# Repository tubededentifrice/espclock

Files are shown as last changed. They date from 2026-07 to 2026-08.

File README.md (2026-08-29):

# ESPClock

A small, child-friendly travel clock: plug it into USB-C and it immediately shows the best time it has, then quietly tries to improve it from an authorized phone or the Internet.

The reference solderless prototype uses a **full-size 38-pin ESP32 DevKit**, a
**0.96-inch 128x64 I2C OLED**, and a **BH1750/GY-302**. A DS3231 is optional for
this bring-up: once synchronized, the ESP keeps time while USB power remains
connected. The compact travel build uses an **ESP32-C3 Super Mini**, preferably
with a larger 1.2-inch TM1637 display and a battery-backed DS3231 after the
behavior has been proven on the bench. The firmware also supports the **ESP32-C3
Super Mini Plus** with a 128x64 OLED. Its dedicated profile keeps the onboard
GPIO8 RGB LED dark.

## Printable case

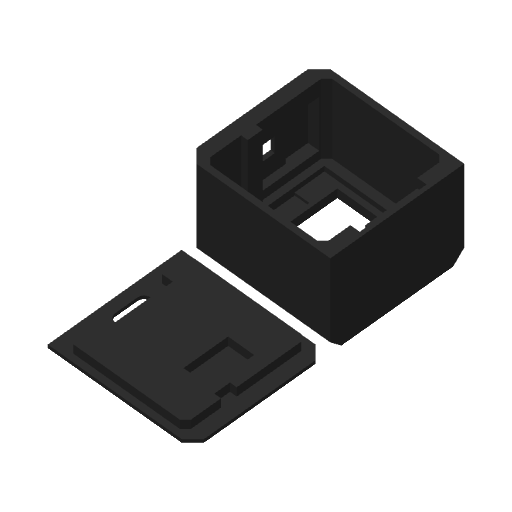
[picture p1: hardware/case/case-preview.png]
ESPClock printable case print plate


The case is checked in as the editable
[Fusion 360 design](hardware/case/esp-clock-case.f3d), a ready-to-slice
[3MF print project](hardware/case/esp-clock.3mf), and individual component
meshes for the [front](hardware/case/front.stl),
[back](hardware/case/back.stl), and [small part](hardware/case/cache.stl).
Use the 3MF for the prepared print plate. The STL files keep design coordinates
and can need placement in the slicer. The preview above comes from the 3MF
print project. This is the current prototype enclosure. Complete the enclosure,
RF, thermal, drop, and child-access acceptance checks below before you use it
as a finished child-facing case.

## What it does

1. Reads UTC from a DS3231 when one is fitted and valid; otherwise it starts
   without inventing a time and waits for a synchronization source.
2. Advertises `ESPClock-xxxx` over BLE continuously. On a clock without a
   selected synchronization route, BLE runs alone for the first 10 seconds.
3. From 10 seconds until two minutes after boot, also offers the no-install
   `ESPClock-xxxx` captive portal while BLE remains available. Loading its
   page transfers the phone's time and offset automatically.
4. If neither phone route succeeds by two minutes, tries open Wi-Fi access
   points in signal-strength order for a bounded window and requests UTC from
   NTP. If NTP is blocked by a captive portal, it makes one bounded,
   synthetic-data-only attempt to accept up to three ordinary guest/terms
   forms, then retries NTP once. A failed BSSID is never retried in that boot.
5. Persists the first successful route. BLE routes refresh every six hours;
   portal and NTP routes wait 24 hours and give BLE a 90-second opportunity
   before using Wi-Fi again. A later successful BLE update promotes any Wi-Fi
   route to BLE and immediately stops Wi-Fi.
6. Keeps time in the ESP while powered and mirrors it to an available RTC.
7. Samples room light about once per second, filters it over several seconds,
   and adjusts the display through eight brightness levels.

Radio failures never stop the clock or blank a valid display.

## Important phone/Bluetooth reality

Approving a Bluetooth pairing authorizes a connection; it does not universally make a phone publish its clock or Internet connection.

- Android does not expose the BLE Current Time Service as a universal system service.
- Generic BLE accessories usually need a phone app to initiate their custom GATT exchange.
- The ESP32-C3 has BLE, not Bluetooth Classic PAN, so it cannot consume Bluetooth tethering.
- NTP provides UTC only. It does not reveal the local timezone.

The repository therefore includes an iOS 18+ [companion app](ios/README.md), an encrypted/bonded BLE write service, and a universal no-app captive-portal fallback. The app uses AccessorySetupKit onboarding and keeps a separate low-duty connection to each authorized clock that has automatic sync enabled, so each clock can request time about every six hours. The app sets no fixed clock-count limit, but iOS radio and memory resources determine the practical number of simultaneous connections. Each clock remembers which route first synchronized it and avoids powering unrelated Wi-Fi paths afterward. BLE remains available as the only automatic route upgrade. Open Wi-Fi/NTP refreshes UTC but retains the last phone-confirmed UTC offset. Concurrent updates are arbitrated atomically in the order BLE, portal, then NTP, so a lower-trust callback cannot overwrite a pending higher-trust update.

This is an honest limit of phone operating systems and profiles, not an ESP32 coding omission. See [hardware research](docs/hardware-research.md) and the [adversarial design review](docs/design-review.md) for sources and deeper tradeoffs.

## Hardware choice

| Board option | Wi-Fi | Bluetooth | Size/fit | Decision |
|---|---:|---:|---|---|
| **ESP32 38-pin** | **Yes** | **Classic + BLE** | Breadboard-friendly, usually Micro-USB | **Selected for the first solderless prototype** |
| **ESP32-C3 Super Mini** | **Yes** | **BLE 5** | **About 22.5 × 18 mm, USB-C** | **Selected** |
| ESP32-C3 Super Mini Plus | Yes | BLE 5 | Same small C3 format; onboard RGB LED and external-antenna connector | Supported 128x64 OLED variant |
| S2 Mini | Yes | No | Small | Rejected: no Bluetooth |
| C6 Mini N4 | Yes, including Wi-Fi 6 | BLE 5.3 | Small | Works, but its extra radios add no clock benefit |

The C3 has enough GPIO, flash, RAM, and radio capability without the size of
the 38-pin board, so it remains the travel target. The firmware has distinct,
pin-safe PlatformIO profiles for both board families and for TM1637, SSD1306
128x64, and SSD1306 128x32 displays.

For OLED bench bring-up, start with the **0.96-inch 128x64** unit. The narrow
0.91-inch module is normally 128x32; with the same 128-pixel width but half as
many rows, its digits are substantially shorter. Neither tiny OLED is
guaranteed readable from two metres, and continuously displayed OLED pixels can
age, so the physical distance/night test decides whether either is suitable for
the final clock. The display backend is modular, so that test does not lock the
firmware to one screen.

## Bill of materials

Prices were checked on **2026-07-25** and are approximate. This regional
snapshot uses UAE prices in AED for a consistent comparison; it does not assume
contributors are in the UAE. Search links and a more detailed comparison are
in [docs/hardware-research.md](docs/hardware-research.md).

| Qty | Part / role | What to buy | Approx. AliExpress | Approx. Amazon.ae |
|---:|---|---|---:|---:|
| 1 | 38-pin ESP32 DevKit | Reference breadboard target | AED 15–30 | AED 25–55 |
| 1 | 0.96-inch SSD1306 OLED, 128x64 | Default bench display, normally `0x3C` | AED 5–12 | AED 15–35 |
| 1 | 0.91-inch SSD1306 OLED, normally 128x32 | Optional comparison display | AED 4–10 | AED 15–30 |
| 1 | BH1750/GY-302 light sensor | Ambient-light input; default address `0x23` | AED 3–8 | AED 10–30 |
| 1 | ESP32-C3 Super Mini or Super Mini Plus | Compact travel target; Plus has an onboard RGB LED | AED 9–18 | AED 20–45 |
| 1 | 1.2-inch red TM1637 clock display | Optional final-display candidate; centre colon | AED 15–40 | AED 35–70 |
| 1 | DS3231 RTC module | Optional for bring-up, required for unplugged retention; verify a non-charging CR2032 arrangement | AED 6–15 | AED 20–45 |
| 1 | Branded CR2032 | Primary, non-rechargeable coin cell | AED 2–5 | AED 5–10 |
| 1 | 5 × 7 cm, 2.54 mm perfboard | Single-sided is sufficient | AED 3–7 | AED 10–20/pack |
| 2 | Female socket strips | Socket the C3 | AED 1–3 | AED 8–15/pack |
| 1 each | 100 µF ≥10 V electrolytic; 100 nF ceramic | Local decoupling | AED 1–2 | Usually in an assortment |
| 1 | USB-C cable and certified 5 V/1 A supply | Use a data-capable cable for flashing | Varies | AED 15–35 |
| — | Solid wire, solder, heat-shrink, smoked red window | Workshop consumables | AED 3–8 allocated | AED 10–25 |

A new bench build using the default ESP32/OLED/BH1750 configuration is roughly
**AED 23–50** from AliExpress. A compact travel build with the C3, TM1637,
BH1750, RTC/cell, perfboard, sockets, and decoupling is roughly **AED 40–98**.
Both estimates exclude shipping, enclosure, cable, and power supply.

Optional only if the exact large display fails its 3.3 V acceptance test: a two-channel BSS138 level-shifter module, approximately AED 2–8.

## Wiring

For the first solderless test, power the OLED and BH1750 from the full-size
ESP32's regulated **3.3 V** rail:

| 38-pin ESP32 | Connect to | Notes |
|---|---|---|
| `3V3` | OLED `VCC`; BH1750 `VCC`; optional DS3231 `VCC` | Keep every I2C pull-up at 3.3 V |
| `GND` | Every module `GND` | One common ground |
| GPIO21 | OLED `SDA`; BH1750 `SDA`; optional DS3231 `SDA` | Shared I2C data |
| GPIO22 | OLED `SCL`; BH1750 `SCL`; optional DS3231 `SCL` | Shared I2C clock |
| GPIO0 | Existing BOOT button only | Five-second powered-on recovery gesture |

Follow the labels printed on the board. Many 38-pin DevKits occupy nearly the
whole breadboard width; use two joined breadboards or jumper one pin row to a
second breadboard if necessary.

The compact TM1637 travel wiring remains:

| ESP32-C3 pin | Connect to | Notes |
|---|---|---|
| `3V3` | TM1637 `VCC`; BH1750 `VCC`; DS3231 `VCC` | Never connect to 5 V |
| `GND` | Every module `GND` | One common ground |
| GPIO4 | TM1637 `CLK` | Dedicated display bus |
| GPIO3 | TM1637 `DIO` | Dedicated display bus |
| GPIO6 | BH1750 `SDA`; DS3231 `SDA` | Shared I2C data |
| GPIO7 | BH1750 `SCL`; DS3231 `SCL` | Shared I2C clock |

Do not attach modules to C3 strapping pins GPIO2/8/9 or native-USB GPIO18/19.
The 128x64 or 128x32 OLED can replace the TM1637 on the C3 by joining it to the
same GPIO6/7 I2C bus. On the Super Mini Plus, GPIO8 drives the onboard WS2812
RGB LED. The dedicated Plus profile sends an all-zero frame after boot. The
power indicator is connected to the power rail and firmware cannot turn it off.

### Travel-build wiring diagram

ESPClock ESP32-C3 Super Mini travel-build wiring

The drawing shows the common top-view Super Mini header order, the four
firmware-selected GPIO connections, both 3.3 V decoupling capacitors, and the
RTC charge-path warning. It also shows the supported 0.96-inch SSD1306 128x64
OLED and notes that the 128x32 OLED uses the same four wires; choose the matching
compile-time profile and fit one display type. This is a routing guide rather
than a 1:1 perfboard artwork; open the image for the full-size SVG and verify
the labels on the exact boards before soldering.

The complete net list, schematic, continuity procedure, level-shifter fallback, and mechanical notes are in [hardware/wiring.md](hardware/wiring.md).

### Mandatory RTC safety check

Many cheap blue ZS-042/HW-111 DS3231 modules try to charge the coin cell through a resistor and diode. A CR2032 is **not rechargeable**.

Before installing a CR2032:

1. prove the module has no charging path, or remove its charge resistor/diode;
2. power the RTC at 3.3 V without a cell and inspect/measure the holder;
3. install the cell, re-power, and verify its voltage is not being driven upward;
4. place it behind a screwed enclosure where a child cannot reach it.

Do not build the clock if this check is uncertain.

### Display voltage acceptance

Running a red TM1637 module at 3.3 V is simple and prevents 5 V pull-ups from reaching the ESP. The TM1637 manufacturer's guaranteed electrical table is specified at higher voltage, so the exact purchased 1.2-inch module must pass:

- repeated cold starts;
- all-segments/full-brightness operation during Wi-Fi transmit;
- two-metre daylight readability;
- minimum-brightness dark-room comfort.

If it fails, follow the 5 V plus BSS138 level-shifter alternative in [hardware/wiring.md](hardware/wiring.md). Never connect a 5 V-powered TM1637 module directly to C3 pins.

## Breadboard bring-up

1. Place the full-size ESP32 on a breadboard and connect the 0.96-inch OLED and
   BH1750 using GPIO21/22. Leave the DS3231 disconnected.
2. Flash `esp32-devkit-oled-128x64`, synchronize from the iPhone app or portal,
   and confirm the clock continues while USB stays powered.
3. Power-cycle it without an RTC. It must return to `PAIR`/`----`, then accept a
   new synchronization normally.
4. Compare the 0.91-inch screen using the separate 128x32 firmware profile.
5. Only then add and qualify a DS3231. Leave the CR2032 out until its charging
   path check is complete.
6. Exercise every brightness level and perform the two-metre/daylight and
   dark-bedroom tests before choosing the final display.
7. Bench-test for at least 24 hours before choosing the compact hardware.

## Later travel assembly

1. Socket the C3 on perfboard with its antenna end at or beyond the board edge.
2. Put the BH1750 at a clear front/top aperture, shaded from the display.
3. Fit 100 µF across display `3V3`/`GND` and 100 nF near the I2C modules.
4. Solder the final wiring and add strain relief; do not leave Dupont jumpers
   in the travel unit.
5. Repeat the 24-hour, radio, brightness, and cold-start tests before treating
   the printed case as final.

Do not pot the first build. If later reinforcement is useful, use printed clips or electronics-safe neutral-cure silicone. Keep the antenna, USB-C connector, sensor aperture, socketed ESP, and coin cell clear and serviceable.

## Build and flash

Host requirements:

- [uv](https://docs.astral.sh/uv/)
- a data-capable cable matching the selected board (normally Micro-USB for the
  full-size DevKit and USB-C for the C3);
- for classic DevKit clones, the CP210x or CH340 USB-UART driver if macOS does
  not already recognize it; the C3 uses its native USB serial/JTAG interface.

The repository accepts a dependency only after it is two weeks old. Python,
PlatformIO, firmware-library, framework, and build-tool dependencies use exact
versions, hashes, or full Git commits. The ESP32-C3 ESP-IDF build also uses the
hash-locked `tools/espidf-python-requirements.txt` file for the Python tools
that PlatformIO normally installs in a separate environment. Do not install
PlatformIO globally.

Run the fail-closed policy check before an install or dependency update. It
verifies the lock hashes and dates against PyPI. It reads PlatformIO and Git
commit dates from their services. It rejects a missing hash, a version range,
a Git tag, or a short Git commit.

```sh
uv sync --locked
uv run --locked opendle-deps check
uv run --locked opendle-pio test -e native
uv run --locked opendle-pio run -e esp32-devkit-oled-128x64
uv run --locked opendle-pio run -e esp32-devkit-oled-128x64 --target upload
```

Use `opendle-pio` for each PlatformIO command. The wrapper runs the policy
check first. For an ESP-IDF environment, it also creates the PlatformIO Python
environment from the hash-locked requirements file.

The same check runs in GitHub Actions. Protect `main` and require the
`Dependency age / check` result so that a change cannot bypass the check. An
urgent security fix that is less than two weeks old needs an explicit policy
change and review. Do not silently remove the cooldown.

PlatformIO normally detects the serial port. If several boards are connected:

```sh
uv run --locked opendle-pio device list
uv run --locked opendle-pio run -e esp32-devkit-oled-128x64 --target upload \
  --upload-port /dev/cu.SLAB_USBtoUART
```

Other common classic-board port names are `/dev/cu.usbserial-*` and
`/dev/cu.wchusbserial*`; C3 boards commonly appear as
`/dev/cu.usbmodemXXXX`.

Open the serial monitor:

```sh
uv run --locked opendle-pio device monitor --baud 115200
```

Normal firmware profiles are optimized release builds and compile application
serial diagnostics out. For a temporary bench build, add
`-D CLOCK_ENABLE_DIAGNOSTICS=1` to the affected profile's `build_flags`, rebuild,
and monitor at 115200 baud. Remove the flag before producing a deployment
image. ESP ROM boot messages can still appear independently of the application
diagnostics flag.

If a clone does not enter download mode automatically, hold its `BOOT` button, tap `RESET`, release `BOOT`, and retry the upload. These buttons are not used in normal clock operation. The existing BOOT button also provides the deliberate recovery gesture described below.

### Qualify a newly received ESP32

Before connecting modules or soldering a board, run the destructive
[incoming-board radio diagnostic](docs/radio-diagnostics.md):

```sh
uv run --locked tools/diagnose_esp.py
```

It erases the board without a confirmation prompt, installs a dedicated
diagnostic image, checks clean boot and Wi-Fi reception, and asks for two
external RF proofs: visibility of its Wi-Fi SSID and an encrypted
write/acknowledgement from the physical-iPhone companion. Only that complete
over-the-air result is reported as `PASS`; internal “started” return values
alone are insufficient.

The default build is the full-size ESP32 + 128x64 OLED bench profile. Available
profiles are:

| PlatformIO environment | Board and display |
|---|---|
| `esp32-devkit-oled-128x64` | 38-pin ESP32, 0.96-inch 128x64 OLED |
| `esp32-devkit-oled-128x32` | 38-pin ESP32, likely geometry of the 0.91-inch OLED |
| `esp32-devkit-tm1637` | 38-pin ESP32, TM1637 on GPIO25/26 |
| `esp32-c3-oled-128x64` | C3, 128x64 OLED |
| `esp32-c3-super-mini-plus-oled-128x64` | C3 Super Mini Plus, 128x64 OLED; GPIO8 RGB LED off |
| `esp32-c3-oled-128x32` | C3, 128x32 OLED |
| `esp32-c3-super-mini` | C3 travel target, TM1637 on GPIO4/3 |
| `esp32-devkit-radio-diagnostic` | Destructive bare-board classic ESP32 acceptance image |
| `esp32-c3-radio-diagnostic` | Destructive bare-board C3 acceptance image |

OLED resolution cannot be identified reliably over I2C. If the 0.91-inch
module is blank or malformed with the 128x32 profile, verify its controller,
address, and listing rather than adding runtime guessing. The default address
is `0x3C`; override `CLOCK_OLED_ADDRESS=0x3D` in a profile if an I2C scan proves
that address.

## Install the iPhone companion

The native Swift companion lives in `ios/` and requires iOS 18 or newer. Open
`ios/ESPClockCompanion.xcodeproj`, select a signing team and your physical
iPhone, then press **Run**. It contains no third-party packages, account,
location permission, network service, advertising, or analytics.

Power-cycle each clock immediately before tapping **Add ESPClock** or **Add
Another ESPClock**. Apple's accessory picker handles the required phone-level
approval. One iPhone can keep automatic sync enabled for many clocks. For each
clock, enable automatic sync on only one family iPhone. Do not force-quit the
app; each connected clock will ask it for fresh time about every six hours. See the
[complete iPhone install, behavior, recovery, and test guide](ios/README.md).

## First use

### RTC already contains valid time

- With a previously selected route, the clock displays it immediately.
- With no previously selected route, `PAIR` marks the two-minute onboarding
  sequence: BLE alone for 10 seconds, then BLE plus the captive portal for
  the remainder. The retained RTC continues running underneath and returns
  to the display as soon as a route succeeds or the initial fallback attempt
  ends.
- BLE advertising remains available for already bonded clients even after the normal time display returns. It uses the proven 30–60 ms discovery cadence during the two-minute onboarding window, then an 800–1000 ms low-duty cadence for later reconnects. New, unbonded phones are accepted for two minutes after boot so Apple's accessory picker has time to complete.
- At 10 seconds, the `ESPClock-xxxx` portal is added without stopping BLE.
- At two minutes, an unsynchronized clock stops the setup portal and shows
  `SEARCHING WIFI` on OLED or `WiFi` on TM1637 while trying last-resort
  open-Wi-Fi/NTP.
- Once a route succeeds, later boots and refreshes use only that route, except
  that an accepted BLE update may always promote a portal/NTP route.

### RTC is new, missing, or lost power

1. The display shows `PAIR` while BLE advertises.
2. After 10 seconds, the open Wi-Fi AP `ESPClock-xxxx` starts alongside BLE;
   the display continues to show `PAIR`.
3. On a phone, join that network before the two-minute mark. As soon as its captive page loads, it reads
   the phone's current time and offset and sets the clock automatically.
4. If the captive page does not open, browse to
   [http://192.168.4.1](http://192.168.4.1). Loading that page is sufficient;
   there is no button or manual time entry.
5. The page sends only Unix UTC and the phone's current UTC offset. It sends no account, Wi-Fi password, location coordinate, or personal data.
6. If neither BLE nor the portal succeeds by two minutes after boot, the
   clock searches open Wi-Fi for a bounded maximum of 10 minutes and asks NTP
   for UTC. On an NTP failure it may run the bounded synthetic captive-portal
   automator described below, then retry NTP once.

The setup AP closes after success or at the two-minute fallback. With no RTC, the clock
continues from the ESP system clock only until USB power is removed. A later
power cycle deliberately returns to the no-time flow and resynchronizes; the
persisted UTC offset alone is not treated as a valid instant.

### Recover from a badly wrong but plausible RTC

The first accepted synchronization can correct an uninitialized clock by any
amount. After a confirmed synchronization, the five-minute correction limit
applies while the ESP or RTC supplies a valid running-time baseline. If total
power loss and an invalid or missing RTC remove that baseline, the next valid
synchronization can set the clock by any amount. The stored confirmation marker
alone cannot provide replay protection without a running baseline.

If the RTC is later wrong by more than five minutes, leave the clock powered
and hold the board's existing `BOOT` button for five seconds. The OLED shows
`RESET`; the four-digit TM1637 approximates `rSt`. Release the button when the
message appears. The full-size ESP32 uses GPIO0 and the C3 uses GPIO9. The
firmware clears the confirmed-sync marker, stored route and offset, and BLE
bonds, then restarts. Do **not** reset or apply power while BOOT is held; that enters the
board's download loader. After restart, use BLE or the portal to set the
correct time and select a new route. The RTC itself is left intact so the screen can continue to show
its best available value until the correction arrives.

This recessed service gesture is not part of normal use. Make the onboard button reachable through a tool/paperclip pinhole in the eventual case.

### After travel to a different timezone

Keep the clock near its authorized iPhone companion; it writes the new
time/offset on reconnect. A clock whose selected route is the captive portal
reopens that portal when its 24-hour refresh becomes due. An NTP-route clock
retries NTP on the same cadence. To choose a different non-BLE route, use the
five-second BOOT recovery gesture. An NTP-only result refreshes UTC but cannot
determine civil timezone by itself.

The current firmware stores a validated offset in 15-minute-capable minutes, not a whole-hour approximation, so zones such as `+05:30` and `+05:45` work. It does not contain the world's timezone/DST database; a phone sync is required after an offset/DST change when the clock has no richer timezone source.

## Display indications

| Display | Meaning |
|---|---|
| OLED `HH:MM`, steady colon | Valid local time; at brightness levels 1–7, even minutes fill the perimeter clockwise and odd minutes erase the same path in 60 equal steps; full-night level 0 switches to a sparse dot-matrix face and suppresses the decorative perimeter |
| TM1637 `HH:MM`, one blink per second | Phone-confirmed local offset this boot |
| TM1637 `HH MM`, brief colon pulse every two seconds | Valid UTC with a retained, not-yet-confirmed timezone offset |
| Steady `PAIR` | Initial two-minute onboarding; after 10 seconds the captive portal is also active |
| `SET` on OLED / `SEt` on TM1637 | A selected portal route is active while no valid time can be displayed |
| OLED `SEARCHING WIFI` / TM1637 `WiFi` approximation | Initial open-network/NTP fallback |
| OLED 3×3 square at the top-right | A periodic refresh is overdue or in progress; the normal time remains steady |
| `----` | No trustworthy time is available yet |
| `RESET` on OLED / `rSt` on TM1637 | BOOT recovery button is being held; keep holding for five seconds, then release |

The initial `PAIR` message remains steady for route selection; it does not
blink or alternate with the retained time. Later periodic refreshes never
replace or blink the valid time. OLED brightness levels 1–7
show only the static 3×3 top-right marker while a refresh is overdue; night
level 0 suppresses the marker entirely. TM1637 keeps its normal clock face and
adds no refresh animation.

## BLE time service

BLE device name: `ESPClock-xxxx`, where the suffix comes from the ESP chip
identifier.

The legacy BLE payload is deliberately split without truncation. The 27-byte
primary advertisement contains general-discoverable/BR-EDR-unsupported flags,
the complete 128-bit service UUID, and preferred connection intervals. Its
15-byte scan response contains the complete `ESPClock-xxxx` local name. Both
remain below the 31-byte limit. Connectability is part of the advertising PDU;
bondability is an SMP security policy, not an advertising-data flag. The
advertising interval is 30–60 ms while new-phone onboarding is open and
800–1000 ms afterward; changing cadence does not remove the name, service UUID,
connectability, or bonded-client reconnect path.

| Item | UUID |
|---|---|
| Service | `7f510000-1b15-4dc7-9f3f-19b30a6f6a21` |
| Time read/write/notify | `7f510001-1b15-4dc7-9f3f-19b30a6f6a21` |
| Status read/notify | `7f510002-1b15-4dc7-9f3f-19b30a6f6a21` |

Time writes require an encrypted/bonded BLE connection. A client may send either:

- UTF-8 text: `unix_utc_seconds,utc_offset_minutes`
- 12-byte binary packet:

| Byte | Value |
|---:|---|
| 0 | protocol version `1` |
| 1–8 | signed Unix UTC seconds, little-endian |
| 9–10 | signed UTC offset minutes, little-endian |
| 11 | flags; reserved on write |

Accepted epochs are 2024-01-01 through 2099-12-31. Offsets must be between UTC−14:00 and UTC+14:00. Malformed, stale-range, oversized, and trailing-junk payloads are rejected.

The status characteristic reports `time-needed`, `sync-request`, `time-pending`, `time-accepted`, `time-rejected`, `rate-limited`, or `invalid-time`. The included iPhone app connects during the two-minute new-phone window for its first bond, enables status notifications, writes the phone's current UTC/offset, waits for `time-accepted`, and retains a low-duty connection. The firmware reissues `sync-request` when notifications are subscribed and approximately every six hours thereafter. The time characteristic includes both the base GATT write property and its encrypted-write requirement. Status values are exact UTF-8 bytes without a trailing NUL; either contract violation breaks Core Bluetooth interoperability even if the clock applies the payload.

BLE bonding capacity is finite even though any family phone may take a turn. This build provisions **16 bond and notification records** and evicts the first bond returned by NimBLE when full so a new family phone can recover the clock. A pairing attempt at capacity must make room before authentication, so a cancelled attempt may evict one existing bond; the acceptance checklist covers this recovery edge case. “Any number of phones” means the clock is not owned by one account or hard-coded handset, not infinite simultaneous connections. Each clock's firmware is compiled for one simultaneous connection, and only one iPhone should leave automatic synchronization enabled for that clock. The iPhone app can hold independent connections to many clocks at the same time.

After the clock has a confirmed-sync marker and a valid running-time baseline,
phone, portal, and NTP corrections must be within five minutes of that time. An
uninitialized clock, or a clock that lost its baseline during total power loss,
can accept one arbitrary valid correction. The BOOT recovery gesture also
reopens that path. This rule rejects captured old values and large corrections
during normal operation. It is not cryptographic replay protection. BLE writes
are also limited to one accepted update per 30 seconds.

BLE uses encrypted **Just Works** bonding because the clock has no input device. The phone shows/owns the approval, but Just Works has no numeric-comparison MITM protection. New unbonded peers are rejected after the two-minute onboarding window. The setup Wi-Fi AP is intentionally open for cross-platform ease, accepts one update, applies the confirmed-clock freshness rule when a valid running baseline exists, then shuts down. These controls fit a low-consequence clock, but they are not equivalent to a per-device cryptographic owner secret.

## Open Wi-Fi/NTP fallback

This is deliberately bounded and contains no credentials:

- only scan results explicitly marked open are considered;
- up to six candidates from one scan are retained in signal-strength order,
  avoiding another full radio scan after each failed association;
- a failed **BSSID** is remembered for this boot and never retried;
- if the fixed 24-entry failure table fills, open-Wi-Fi fallback is disabled for the rest of that boot;
- association and NTP have fixed timeouts;
- each NTP fallback window is capped at 10 minutes and NTP-route failures then
  back off for 24 hours;
- after the first NTP failure on a BSSID, an HTTP connectivity probe detects
  interception; the clock may follow at most five redirects and submit at most
  three same-origin URL-encoded forms within 45 seconds;
- the form parser uses fixed capacities (16 KiB response, 2 KiB request, four
  forms, 24 controls, six cookies/1 KiB total) and rejects overflow, malformed
  framing, JavaScript-only actions, credentials, CAPTCHA/OTP, file uploads,
  payment, voucher, membership, reservation, and room-number flows;
- accepted guest/terms forms receive only a random per-attempt synthetic
  identity such as `Travel Clock`, an `@example.com` address, and a reserved
  `+1 202-555-01xx` phone number; identified terms/conditions boxes are
  accepted, optional marketing choices stay clear, and unknown required
  choices fail closed;
- HTTPS certificate verification is deliberately disabled only inside this
  disposable-data portal worker because trustworthy UTC may not exist yet;
- no SSID/password is saved;
- the station MAC is randomized once per boot before joining opportunistic networks;
- no admin interface, telemetry, OTA, or child/family information is exposed;
- successful NTP updates UTC while retaining the last confirmed offset.

The worker runs outside the main loop, so BLE, the display, and recovery button
remain responsive. A genuine HTTP 204 after the first NTP failure is treated as
Internet access with UDP/123 blocked and the BSSID is skipped; a successful
form flow still has to pass the normal NTP and time-plausibility checks. No
portal cookies or identity survive the attempt, and successful time remains an
`NTP` source rather than a portal time source.

[RFC 8908](https://www.rfc-editor.org/info/rfc8908) defines the CAPPORT API and
[RFC 8910](https://www.rfc-editor.org/info/rfc8910) defines captive-portal
identification including DHCP option 114, but neither standard defines portable
HTML form semantics. The pinned Arduino/lwIP stack does not expose option 114
without a framework modification, so this implementation deliberately retains
the intercepted HTTP `generate_204` probe as its discovery mechanism.

Open networks are untrusted, terms and form shapes vary, and this automation is
only a best-effort last resort. Disable all open-Wi-Fi use, or only form
automation, with:

```ini
-D CLOCK_ENABLE_OPEN_WIFI_FALLBACK=0
-D CLOCK_ENABLE_CAPTIVE_PORTAL_AUTOFILL=0
```

## Automatic brightness

The BH1750 is triggered in high-resolution one-shot mode and sampled every
second, returning to its power-down state between measurements. An exponential
filter gives roughly a several-second response and 20% hysteresis prevents
flicker near level boundaries. The normalized eight levels map directly to
TM1637 brightness and to a visibly separated SSD1306 contrast curve. Because
some small OLED modules show little perceived change across their contrast
range, the SSD1306 backend also uses flicker-free spatial dimming. Full-night
level 0 uses contrast code 1, renders each 5×7 source-font point as one widely
spaced OLED pixel across the same digit footprint as levels 1–7, and suppresses
the decorative seconds perimeter. Contrast code 0 blanked the tested panel, so
it is not treated as a usable brightness step. Temporary status text at level 0
retains 1/16 pixel coverage. Levels 1–7 use the large connected-stroke face,
rising from 25% coverage at level 1 to 100% at level 7. A fully covered sensor
reading around 0.83 lux settles to level 0; the sensor-missing fallback level 2
retains 37.5% coverage. At levels 1–7 the
one-pixel seconds perimeter is sampled separately along its clockwise path so
low coverage cannot erase an entire screen edge. Firmware first tries the
configured BH1750 address and then the other valid address (`0x23`/`0x5C`). If
the BH1750 is absent, cannot start its next one-shot measurement, or stops
producing valid, ready samples, the display remains usable at fallback level 2
and the sensor is retried every 30 seconds.

For bench diagnosis, temporarily build the affected profile with both
`CLOCK_ENABLE_DIAGNOSTICS=1` and `CLOCK_LIGHT_DIAGNOSTICS=1` to log each raw and
filtered lux sample, selected level, and SSD1306 contrast command at 115200
baud. Normal profiles compile these diagnostics out.

Tune the following in `include/AppConfig.h` or with PlatformIO `-D` flags:

- pin assignments and BH1750 address;
- main-loop delay and optional CPU frequency;
- BLE advertising, 10-second BLE-only grace, two-minute initial setup,
  six-hour BLE resync, 24-hour Wi-Fi resync, 90-second BLE promotion grace,
  and bounded NTP timings;
- light sample interval;
- application and verbose light diagnostics;
- fallback UTC offset;
- open Wi-Fi and captive-portal autofill enable/disable, maximum submissions,
  and total autofill timeout.

For a red TM1637, use a smoked red acrylic window or neutral-density film if
brightness code 0 still lights the room. Bench-tune the OLED minimum contrast
before enclosure work. Do not use slow visible blinking as a dimming
substitute.

## Power behavior

The C3 travel profiles use an 80 MHz maximum CPU clock and reduce it to 40 MHz
while the processor is idle. Hardware and system locks return the CPU to the
required frequency for active work. The classic breadboard profiles retain
their normal clock because they are bring-up targets. The main task yields for
20 ms instead of polling every 5 ms, and both display backends avoid
retransmitting an unchanged frame. The level-0 night face suppresses the OLED
perimeter, but its one-minute cadence at levels 1–7 is unchanged. These changes
do not alter the 250 ms display policy, TM1637 colon cadence, portal service,
recovery gesture, or BLE callbacks.

The C3 application profiles build Arduino as an ESP-IDF component with
the checked-in `sdkconfig.c3.defaults`. This enables 80/40 MHz dynamic
frequency scaling and Bluetooth controller modem sleep, so the processor and
radio reduce power between events. The production log level also suppresses
ESP-IDF information messages that would otherwise do repeated serial work
during TM1637 updates.

The selected route controls later radio use. BLE routes request a refresh every
six hours and never start Wi-Fi. Portal and NTP routes wait 24 hours, request
BLE first, and allow 90 seconds for an accepted BLE update. Success promotes
the route to BLE and shuts Wi-Fi down; otherwise a portal route leaves its
SoftAP/page available until a phone loads it, while an NTP route performs one
bounded open-network attempt of at most 10 minutes and then backs off for
another 24 hours. Failed BSSIDs remain excluded for the rest of that boot.

Periodic refresh never replaces or blinks a valid clock face. OLED levels 1–7
add a static 3×3 top-right stale-time marker until a refresh succeeds. Level 0
and TM1637 add no light or animation. BLE advertising and bonded reconnect
remain available throughout Wi-Fi activity; the ESP32 coexistence scheduler
time-shares the single 2.4 GHz radio.

Automatic CPU light sleep and deep sleep are not used because they can stop
display updates or break the persistent BLE relationship, continuous
recovery-button handling, and normal radio callbacks. Dynamic frequency
scaling does not suspend the CPU. BLE transmit power, advertising intervals,
connected intervals, and all refresh rules are unchanged. Whole-device
consumption still depends heavily on the exact display module, brightness,
board regulator, and indicator LEDs, so measure the assembled travel build
rather than extrapolating from the bare ESP32-C3.

On 2026-07-30, one C3 Super Mini with a 128x64 OLED at fallback brightness
level 2 measured 0.08 W after BLE synchronization. The BH1750 was disconnected.
This is one bench result, not a guaranteed value for other boards or displays.

## Firmware layout

| Path | Responsibility |
|---|---|
| `src/main.cpp` | Atomically prioritized time-update integration and visible-state selection |
| `src/TimeKeeper.cpp` | UTC system clock, DS3231, and persisted offset |
| `src/BleTimeService.cpp` | Bonded BLE GATT time/status service |
| `src/NetworkTimeService.cpp` | Captive setup portal, open-Wi-Fi backoff, portal-worker integration, and NTP |
| `src/CaptivePortalAutofill*.cpp` | Bounded HTTP worker plus host-testable URL/form/encoding policy |
| `src/DisplayController.cpp` | Display-independent visible-state and BH1750 brightness policy |
| `src/*DisplayBackend.cpp` | Modular TM1637 and SSD1306 rendering backends |
| `src/ClockCore.cpp` | Host-testable payload validation and light filtering |
| `test/` | Native Unity tests |
| `hardware/` | Wiring authority and protoboard placement |
| `hardware/case/` | Fusion 360 case source, 3MF print project, component STL exports, and print-plate preview |
| `docs/` | Research and adversarial review |
| `ios/` | iOS 18+ AccessorySetupKit/Core Bluetooth companion and packet tests |
| `AGENTS.md` | Repository-wide agent instructions |
| `.codex/skills/maintain-espclock/` | Repo-local maintenance workflow for coding agents |

External embedded libraries are version-pinned in `platformio.ini`. The
SSD1306 profiles use the pinned Adafruit SSD1306, GFX, and BusIO libraries.
Their connected-stroke 5×7 numeric glyphs maximize panel height without the
hard-to-read gaps of a simulated seven-segment display. OLED brightness level 0
reuses the same full-size glyph footprint as a sparse, one-pixel dot matrix for
full-night use. Host tooling is locked by uv.

## Acceptance checklist

For every incoming ESP32, first obtain a complete `PASS` from
`tools/diagnose_esp.py`; see the
[radio diagnostic pass/fail rules](docs/radio-diagnostics.md). The checks below
then qualify the assembled clock and its enclosure.

Do not close or pot the case until every applicable physical item passes.

### Automated

- [x] `uv run --locked opendle-pio test -e native` passes (53/53).
- [x] `uv run --locked python -m unittest discover -s tools/tests` passes the nine
  diagnostic-runner parser and classification tests.
- [x] `uv run --locked opendle-pio run -e
  esp32-devkit-oled-128x64` completes.
- [x] All seven display/board profiles compile in the final verification matrix.
- [x] Both classic ESP32 and C3 radio-diagnostic profiles compile.
- [x] No ESPClock source warnings are reported. The pinned Arduino I2S
  framework, which ESPClock does not use, emits missing-field-initializer
  warnings in ESP-IDF C3 builds.
- [x] Normal icon-inclusive Swift app and test-bundle builds complete for a
  generic iPhone target.
- [x] All 29 multi-clock packet, preference, and onboarding-lifecycle XCTests
  pass on the iOS 26.5 Simulator.

### Power, display, and sensor

- [ ] USB cold-start succeeds 20 times without pressing a button.
- [ ] Both OLED profiles render correct, centered four-digit time, steady colon,
  the full-size sparse level-0 night face, the level-1–7 top-center 60-step
  alternating perimeter, the two-line `SEARCHING WIFI` message, and all other
  status words.
- [ ] The 3×3 overdue-sync marker occupies the top-right pixels at levels 1–7,
  remains steady through BLE/portal/NTP retries, and is absent at level 0.
- [ ] 0.96-inch and 0.91-inch displays are compared at two metres in daylight.
- [ ] Minimum brightness remains readable but does not illuminate a dark bedroom.
- [ ] BH1750 responds smoothly over dark, bedroom, room, and daylight conditions.
- [ ] Display light does not materially feed back into the BH1750.
- [ ] Whole-device current and peak current are recorded for BLE advertising,
  BLE connected, portal, Wi-Fi/NTP, and display brightness levels 0/2/7.
- [ ] On each C3 display profile, Bluetooth reconnect and time sync work after
  at least 30 minutes with Bluetooth modem sleep active.
- [ ] On a C3 Super Mini Plus, the RGB LED stays dark from firmware startup
  through BLE and Wi-Fi activity. The fixed power indicator remains on.
- [ ] The C3 remains stable with 80/40 MHz dynamic frequency scaling through a
  24-hour soak, repeated portal use, BLE reconnects, and Wi-Fi/NTP attempts.
- [ ] Selected board regulator and wiring remain comfortably below unsafe temperature.

### RTC and safety

- [ ] Missing DS3231 boots, synchronizes, keeps time while powered, and returns
  to no-time/pairing after complete power loss.
- [ ] DS3231 loss-of-power state is detected when the module is later fitted.
- [ ] RTC retains time after one hour and 24 hours unplugged.
- [ ] Powered VBAT measurement proves the CR2032 is not being charged.
- [ ] Coin cell and solder joints are inaccessible without tools.
- [ ] USB cable has strain relief; the connector is not structural.

### Time and recovery

- [ ] Invalid RTC never displays a plausible invented time.
- [ ] Portal sync starts on page load without a tap and works on at least one
  current iPhone and one current Android phone.
- [ ] On a cleared clock, BLE runs alone for 10 seconds, then coexists with the
  setup portal until the two-minute open-Wi-Fi/NTP fallback.
- [ ] BLE, portal, and NTP first successes persist the matching route across
  reboot; a later BLE success promotes either Wi-Fi route and stops Wi-Fi.
- [ ] BLE routes refresh at six hours without starting Wi-Fi. Portal/NTP routes
  wait 24 hours, allow the 90-second BLE promotion grace, then use only their
  selected Wi-Fi route.
- [ ] An overdue portal route leaves the setup AP/page available until success;
  an NTP route is bounded to 10 minutes and then backs off for 24 hours.
- [ ] BLE write works after first bond and after reconnect.
- [ ] A second family phone can also bond/write.
- [ ] All 16 bond/notification slots survive reboot/reconnect; adding or cancelling a 17th pairing follows the documented eviction/recovery behavior.
- [ ] AccessorySetupKit onboarding works on physical iOS 18 and current iOS.
- [ ] An independent BLE scanner shows the complete name/service UUID and a
  connectable advertisement throughout the two-minute `PAIR` window.
- [ ] A scanner confirms the 30–60 ms onboarding cadence changes to
  800–1000 ms after the window, and a bonded iPhone still reconnects from the
  background at five metres.
- [ ] Locked/background iPhone answers a six-hour `sync-request`.
- [ ] Core Bluetooth restores after system termination, without user force-quit.
- [ ] One iPhone maintains simultaneous connections to at least three clocks;
  each clock reconnects, requests, acknowledges, and reports errors without
  changing another clock's state.
- [ ] Disabling or removing one clock leaves the other clock connections active.
- [ ] Two iPhones can hand off one clock using that clock's automatic-sync
  toggle.
- [ ] Bad epoch, bad offset, oversized payload, and trailing junk are rejected.
- [ ] A plausible RTC that is hours wrong can be recovered with the five-second BOOT gesture and corrected without a computer.
- [ ] UTC−12, UTC+14, `+05:30`, and `+05:45` display correctly.
- [ ] Open Wi-Fi association failure does not retry that BSSID before reboot.
- [ ] One fallback window performs one Wi-Fi scan and attempts its retained
  open candidates without rescanning between failures.
- [ ] On an operator-controlled captive network, button-only, hidden-token,
  synthetic name/email/phone, terms-checkbox, cookie/redirect, three-step, and
  self-signed-HTTPS forms either unlock NTP or fail within the documented
  bounds.
- [ ] JavaScript-only, malformed, oversized, credential, CAPTCHA/OTP, payment,
  voucher, membership, reservation, and room-number portals fail closed and
  return to the clock without retrying that BSSID.
- [ ] BLE synchronization during portal HTTP activity cancels the worker,
  stops Wi-Fi, ignores its stale result, and leaves the valid display steady.
- [ ] With all radios unavailable, valid RTC time remains displayed.
- [ ] With the selected source unavailable for two refresh cycles, the display
  never leaves or blinks the normal time; only the non-night OLED marker
  indicates that synchronization is overdue.

### Enclosure/RF

- [ ] BLE and Wi-Fi work at five metres with intended case materials in place.
- [ ] No copper, cell, fastener, epoxy, or metal blocks the C3 antenna.
- [ ] BH1750 aperture, USB-C, and RTC cell remain serviceable.

## Known limitations

- The included app is iPhone-only and requires iOS 18+. iOS background BLE is event-driven and best-effort: force-quitting the app, disabling Bluetooth, leaving range, expired development signing, or some reboot/first-unlock states stop updates until the app can run again. The DS3231 and captive portal are the resilience layers.
- One iPhone can own persistent BLE sync connections to many clocks. Each clock
  still accepts only one connected iPhone, so other authorized family phones
  can take over that clock only after automatic sync is disabled on the active
  phone.
- The first successful source is sticky to avoid unnecessary radio power:
  portal and NTP routes do not automatically switch to one another. BLE may
  always promote either route; the BOOT recovery gesture clears the route.
- When a portal-route refresh is overdue, its intentionally open local setup
  AP remains available until a valid update arrives. It exposes only the
  bounded time-submission page, but nearby devices can see and join the AP.
- The current phone payload stores the present UTC offset, not a complete IANA timezone/DST rule. Re-sync after travel or DST changes.
- Open-Wi-Fi portal automation deliberately accepts ordinary guest/terms forms
  with synthetic data and unverified portal TLS. It cannot execute JavaScript,
  solve challenges, supply credentials or payments, or guarantee that a
  network operator permits automated acceptance. NTP is not authenticated.
- Cheap C3, DS3231, BH1750, OLED, and large TM1637 modules vary. The 0.91-inch
  unit may even use an SH1106-compatible controller despite its listing.
  Qualify the exact parts before sealing a child-facing build.
- The C3 Super Mini Plus power indicator has no GPIO control. The dedicated
  profile turns off the GPIO8 RGB LED only. A dark power indicator needs a
  board-level change, such as removal of its LED or series resistor.
- An always-on OLED can suffer uneven pixel aging. The supported small OLEDs
  are excellent for solderless bring-up, but the larger TM1637 remains the
  leading final-display candidate until the two-metre and long-duration tests
  pass.
- A four-digit display provides no numeric seconds or named timezone. At OLED
  brightness levels 1–7, the perimeter gives quiet seconds progress but does
  not expose timezone freshness; full-night level 0 omits that decorative
  progress. The TM1637 colon cadence and serial log provide that diagnostic.

These limits are why the RTC plus no-app portal are retained: the clock remains recoverable without pretending iOS guarantees continuous execution.

## Development rules

Future agents and contributors must read [AGENTS.md](AGENTS.md) and the repo-local [maintain-espclock skill](.codex/skills/maintain-espclock/SKILL.md). In particular:

- use `uv` for all Python work;
- keep code, pins, BOM, wiring, and visible states synchronized;
- never charge a CR2032;
- never claim generic BLE pairing automatically transfers time;
- run native tests and the C3 build before handoff.

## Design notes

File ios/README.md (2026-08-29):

# ESPClock iPhone companion

This iOS 18+ app gives each added clock regular, timezone-aware synchronization
without an Internet connection. It uses Apple's AccessorySetupKit for one-tap
onboarding. It then keeps one low-duty Bluetooth LE connection to each clock
that has automatic sync enabled, through one Core Bluetooth central manager.
Each ESP clock requests a fresh phone time about every six hours. A status
notification can wake the suspended app so it can answer.

The app has no account, server, advertising, analytics, location permission, or
third-party dependency. It sends only the iPhone's Unix time and the current UTC
offset to the authorized clock.

## Requirements

- an iPhone running iOS 18 or newer;
- Xcode 16 or newer on a Mac;
- a free or paid Apple developer account selected in Xcode;
- the ESPClock firmware from this repository already flashed;
- Bluetooth enabled on the iPhone.

BLE does not work in the iOS Simulator. Final pairing and background behavior
must be tested on a physical iPhone.

## Authorization lifecycle

Fresh launch activates only `ASAccessorySession`. The app does not construct
`CBCentralManager` until AccessorySetupKit has authorized at least one clock:

1. the picker is presented with no central manager in the process;
2. `.accessoryAdded` retains the selected accessory but does not connect;
3. `.pickerDidDismiss` creates one central manager and uses all authorized
   accessories' `bluetoothIdentifier` values to retrieve and connect them;
4. `.activated` creates the manager immediately only when the session already
   contains one or more authorized clocks.

This ordering lets AccessorySetupKit authorize the first accessory without
asking for broad access to nearby Bluetooth devices. The same picker can then
add more clocks without stopping existing clock connections. The app retains
the `bluetooth-central` background mode and its stable, per-install restoration
identifier. On a fresh install, picker cancellation or failure leaves no scan,
connection attempt, or central manager.
The information property list intentionally carries both
`NSAccessorySetupSupports` and `NSAccessorySetupKitSupports`: current
documentation names the former, while a physical iPhone on iOS 26.5.2
runtime-validates the latter and terminates session activation if it is absent.

## Install on an iPhone

1. Open `ios/ESPClockCompanion.xcodeproj` in Xcode.
2. Select the **ESPClockCompanion** target, open **Signing & Capabilities**, and
   choose your development team.
3. Confirm that the bundle identifier is `com.opendle.espclock`. This identifier
   must belong to the selected Apple developer team before an App Store or
   TestFlight upload.
4. Connect and unlock the iPhone, select it as the run destination, and press
   **Run**.
5. Accept the iPhone's trust/developer-mode prompts if this is the first local
   app you have installed.

A free personal team is sufficient for development-device testing, but its
provisioning expires and the app must periodically be rebuilt. For durable
family installation, use a paid Apple Developer account and distribute through
the App Store, an unlisted App Store listing, or another Apple-approved method.
TestFlight builds also expire.

## Pair the clock

1. Power-cycle the clock that you want to add.
2. Open **ESPClock** and tap **Add ESPClock** or **Add Another ESPClock** while
   that clock accepts new phones—during the first two minutes after boot.
3. Select `ESPClock-xxxx` in Apple's accessory picker and approve Bluetooth
   pairing.
4. Wait until the app says **Connected and synchronized**.
5. Repeat these steps for each additional clock.

Each clock section title uses the complete Bluetooth name, such as
`ESPClock-06E8`. The app reads this name from the advertisement or the standard
GAP Device Name value and saves it for later launches.

The no-app portal starts 10 seconds after boot if BLE has not synchronized. It
stays available until the initial two-minute fallback starts. If the picker
finds nothing, unplug and reconnect the clock, then try once more nearby.

Before the first authorization, the app says **Ready to add clock**. While
Apple's picker is open, it says **Finding accessories…**. **Turn on Bluetooth**
appears only after authorization when the central manager reports
`.poweredOff`; `.unauthorized`, `.unsupported`, `.resetting`, and `.unknown`
have separate messages.

## Normal behavior

- Leave **Keep synchronized** enabled for each clock that this iPhone owns.
- The app has no fixed clock-count limit. It keeps separate connection,
  acknowledgement, retry, and last-sync state for every authorized clock.
- It is safe to leave the app in the background; do not swipe it away.
- The app sends time to each clock immediately after that clock reconnects.
- While connected, each clock asks for another update every six hours.
- After a clock power cycle, iOS automatically reconnects to that clock when
  the phone is in range and the operating system permits it.
- Each clock has its own **Sync Now**, automatic-sync switch, last-sync value,
  status, and remove action.
- A removal confirmation opens from the selected clock's **Remove Clock**
  button and names that clock.
- Each clock's DS3231 keeps time when no phone is nearby, so missed BLE updates
  do not stop a clock.

One iPhone can keep automatic sync enabled for many clocks at the same time.
However, only one iPhone should keep automatic sync enabled for a given clock.
Each ESP clock permits one active synchronization connection. Turn off that
clock's switch on the current phone before another authorized family phone
takes ownership of it.

The app does not set an artificial maximum number of clocks. The practical
number of live Bluetooth connections depends on iOS radio and memory resources,
the radio environment, and whether all clocks are in range.

## What iOS cannot guarantee

The design uses `bluetooth-central`, a stable Core Bluetooth restoration
identifier, AccessorySetupKit authorization, notification subscriptions, and
iOS automatic reconnect. These are the supported mechanisms for background BLE,
but they are event-driven—not a guaranteed six-hour timer.

Background synchronization stops when:

- the user force-quits the app from the app switcher;
- Bluetooth is disabled or permission is revoked;
- the phone and clock are out of range;
- the app is uninstalled or its signing/provisioning expires;
- iOS has not yet allowed apps to run after a phone reboot/first unlock.

Open the app once to recover after those conditions. The clock continues from
its RTC and still offers the no-app captive portal after boot.

Starting with iOS 26, Bluetooth state-restoration relaunch is available only for
accessories originally onboarded through AccessorySetupKit. That is why this app
requires iOS 18+ and does not use a custom in-app scanner for first setup.

## Remove or recover

Each **Remove Clock** action revokes only that clock's iPhone-side
AccessorySetupKit authorization. Other clocks stay connected. The removed ESP
may still retain its BLE bond. If adding it again fails, keep the clock powered
and hold its recessed **BOOT** button for five seconds until `RESET` appears on
OLED or `rSt` on TM1637, then release it. The full-size ESP32 uses its GPIO0
button and the C3 uses GPIO9. The clock clears bonds and restarts; then add it
again within two minutes. This also resets the confirmed timezone and
anti-large-correction marker, so use it only for recovery.

## Protocol and implementation

The app subscribes to the status characteristic before writing a 12-byte,
little-endian packet with response:

| Byte | Value |
|---:|---|
| 0 | protocol version `1` |
| 1–8 | signed Unix UTC seconds |
| 9–10 | signed UTC offset minutes |
| 11 | reserved flags, currently zero |

It accepts `time-accepted` as the application-level acknowledgement and performs
a status read if that notification is delayed. Each clock has an independent
acknowledgement deadline and bounded retry sequence. One central manager owns
all clock peripherals and restores all connected or pending peripherals after
an eligible iOS relaunch. The OS owns long-range pending reconnect behavior.
Firmware status values are exact UTF-8 bytes without a trailing NUL. The time
characteristic advertises the base GATT write capability and separately
requires an encrypted link; both properties are necessary for Core Bluetooth
to permit `.withResponse` writes.

## Reproduce and capture onboarding diagnostics

Use a physical iPhone attached to Xcode. Delete the app first, remove any Kids
Clock entry under **Settings → Privacy & Security → Accessories**, then use the
five-second powered-on BOOT recovery gesture to clear the ESP's bonds. Do not
hold BOOT while applying power.

1. In Xcode, run the rebuilt app on the unlocked iPhone and show the debug
   console.
2. Start the firmware serial monitor with
   `uv run --locked opendle-pio device monitor --baud 115200`.
3. Power-cycle the ESP and confirm its serial log says `[BLE] advertising
   start=ok`; `PAIR` alone is not proof of a successful radio start.
4. Confirm the app initially says **Ready to add clock**. Bluetooth should be
   enabled globally; the app should be managed under the Accessories privacy
   page rather than receiving access to every nearby Bluetooth device.
5. Tap **Add ESPClock**, exercise setup or cancellation, and save both logs.

The Xcode category `BLEOnboarding` records every `ASAccessorySession` event,
every `CBCentralManager` state transition, picker error domain/code, and whether
a central manager existed when the picker opened or appeared. It deliberately
does not log Bluetooth identifiers. The expected fresh-install sequence is:

```text
Accessory session event=activated centralManagerExists=false
Opening accessory picker; centralManagerExists=false
Accessory session event=pickerDidPresent centralManagerExists=false
Accessory session event=accessoryAdded centralManagerExists=false
Accessory session event=pickerDidDismiss centralManagerExists=false
Creating post-authorization central manager
Central manager state=poweredOn
```

When you add a later clock, the existing central manager and clock connections
remain active while the picker is open. The fresh-install sequence above still
has `centralManagerExists=false`.

The earlier failure symptom to compare against is: system Bluetooth on, the app absent
from broad Bluetooth privacy settings, an empty picker, and a manager created
before authorization reporting `.poweredOff`. That baseline still requires an
actual fresh-install capture; the generic-device build cannot reproduce a
physical radio/privacy state.

Picker failures appear in the UI and log as an error domain and numeric code.
This preserves actionable detail without displaying or logging accessory
identifiers.

## Independently verify the advertisement

Before evaluating the picker, inspect the ESP with an independent BLE scanner
on a second phone or Mac. During the two-minute `PAIR` window confirm:

- complete local name `ESPClock-xxxx`;
- complete service UUID `7F510000-1B15-4DC7-9F3F-19B30A6F6A21`;
- a connectable legacy advertisement that continues throughout the window.

The onboarding advertisement remains at the previously qualified 30–60 ms
interval. When the two-minute window closes, the same name, UUID, scan response,
and connectable PDU continue at an 800–1000 ms interval for lower-duty bonded
reconnects. Confirm both cadences over the air; an API log is not sufficient.

The firmware explicitly emits a 27-byte primary advertisement: 3-byte
general-discoverable/BR-EDR-unsupported flags, 18-byte complete 128-bit service
UUID field, and 6-byte preferred-connection-interval field. The 15-byte scan
response contains the complete 13-byte name plus its field overhead. Both are
below the 31-byte legacy packet limit.

BLE has no general “pairable” advertising-data bit. The connectable PDU can be
confirmed in a scanner; bondability is confirmed when AccessorySetupKit connects
and the firmware log reports `authentication requested` followed by
`authentication complete ... bonded=yes`. The firmware also logs advertising
start/recovery, connections, privacy-safe authentication state, numeric
disconnect reasons, and whether advertising remained active when the pairing
window closed. Repeated failed/rejected connection storms are rate-limited and
report a suppressed-event count. It never logs peer addresses or authentication
material.

The app intentionally retains the legitimate service-UUID-plus-name discovery
descriptor first. If a current physical iOS release still shows an empty picker
after this lifecycle fix and the scanner proves the advertisement is correct,
the next experiment is a compact service-data blob/mask marker using this same
service UUID. Recalculate both packet sizes before that experiment. Do not use
Espressif's or any other organization's Bluetooth Company Identifier. If a
registered company identifier proves empirically mandatory, stop and choose a
properly assigned and registered option before changing firmware or app
filters.

## Build checks

Compile the unsigned app and its test bundle for a generic device:

```sh
xcodebuild \
  -project ios/ESPClockCompanion.xcodeproj \
  -scheme ESPClockCompanion \
  -configuration Debug \
  -sdk iphoneos \
  -destination 'generic/platform=iOS' \
  -derivedDataPath /private/tmp/espclock-ios-derived \
  CODE_SIGNING_ALLOWED=NO \
  build

xcodebuild \
  -project ios/ESPClockCompanion.xcodeproj \
  -scheme ESPClockCompanion \
  -configuration Debug \
  -sdk iphoneos \
  -destination 'generic/platform=iOS' \
  -derivedDataPath /private/tmp/espclock-ios-tests-derived \
  CODE_SIGNING_ALLOWED=NO \
  build-for-testing
```

The XCTest cases validate the firmware packet's byte order and input bounds,
plus fresh-install lifecycle ordering, cancellation, multi-clock authorized
relaunch, later-clock addition, picker failure isolation, radio-state
messaging, and per-clock removal cleanup.
Run them on a compatible iOS Simulator or selected physical device from Xcode.

The normal icon-inclusive app build, test-bundle build, and all 29 Simulator
tests pass with the documented toolchain. These tests include six packet, three
per-clock preference, one identity-presentation, 12 onboarding lifecycle, four
acknowledgement-state, one status-decoding, and two reconnect-state cases. If a Mac
reports a CoreSimulator framework mismatch or `iOS ... is not installed`, run
Xcode once, finish **Xcode → Settings → Components**, or use
`xcodebuild -runFirstLaunch` followed by `xcodebuild -downloadPlatform iOS`.
The platform download can be several gigabytes.

## Physical acceptance tests

Record the actual versions rather than substituting an SDK or Simulator result:

| Test device | iPhone model | iOS version | App build | Result/date |
|---|---|---|---|---|
| Oldest supported | Not yet tested | Not yet tested | local Debug | Pending |
| Current release | iPhone 17 Pro | iOS 26.5.2 | local Debug | Fresh onboarding, assembled-display time, reboot reconnect, remove/re-add, manual sync, `time-accepted`, and `+240` offset passed with a qualified C3 (2026-07-25) |

For each applicable physical iPhone:

- delete the prior app/Accessory authorization and clear ESP bonds with the
  powered-on BOOT gesture;
- verify fresh-install picker discovery during `PAIR`, approval, connection,
  `time-accepted`, correct local civil time, and current UTC offset;
- compare Xcode and firmware logs with the expected lifecycle above;
- test picker cancel/retry and picker failure recovery;
- remove and re-add the clock, including ESP bond recovery;
- test ESP reboot reconnect, walk out of range/back in range, and **Sync Now**;
- add at least three clocks, keep all three connected, and prove that each
  clock receives and acknowledges its own update;
- power-cycle and move each of the three clocks out of range separately; prove
  that one clock's retry and acknowledgement state does not change the others;
- disable automatic sync and remove one clock; prove that the other clocks
  remain connected and continue to synchronize;
- after the two-minute window, confirm the 800–1000 ms low-duty advertisement
  still restores a bonded background connection at five metres;
- test locked/background reconnection and a six-hour `sync-request`;
- test Core Bluetooth restoration after system termination, separately from an
  intentional force-quit;
- test handoff of one clock between two authorized family iPhones by using that
  clock's automatic-sync switch;
- fill all 16 bond/notification slots, cancel one at-capacity pairing, and
  verify recovery;
- verify no location, Internet service, account, analytics, third-party SDK, or
  broad Bluetooth-scanning authorization was introduced;
- test the captive-portal fallback with the app unavailable.

As of this repository update, the unsigned app and test bundle are built with
Xcode 26.6 and the iOS 26.5 SDK. A signed fresh install was launched
successfully on the iPhone 17 Pro above after its development profile was
trusted. That launch caught a physical-device-only iOS 26.5.2 requirement for
the compatibility `NSAccessorySetupKitSupports` key; the app now retains it
alongside `NSAccessorySetupSupports`.

On a qualified bare ESP32-C3 Super Mini, independent Mac scans received the
complete service UUID/name advertisement at -45 dBm and the real
`ESPClock-06E8` SoftAP at -35 dBm. The physical iPhone picker then discovered
and authorized the clock without broad Bluetooth access; firmware recorded a
bonded encrypted connection and accepted the phone time with a `+240` minute
offset, and the app received `time-accepted`. A comparison C3 could receive
nearby Wi-Fi but transmitted neither a minimal BLE advertisement nor a minimal
SoftAP at 5–10 cm, proving that board's RF transmit path was defective rather
than an app filter failure. After installing the qualified C3, the assembled
display showed correct local time, app removal/re-add worked, an ESP reboot
reconnected and synchronized automatically, and manual **Sync Now** was
accepted. Out-of-range return, locked/background restoration, and the six-hour
request remain explicit device gates.

Apple references: [AccessorySetupKit](https://developer.apple.com/documentation/accessorysetupkit/),
[Core Bluetooth background processing](https://developer.apple.com/library/archive/documentation/NetworkingInternetWeb/Conceptual/CoreBluetooth_concepts/CoreBluetoothBackgroundProcessingForIOSApps/Perform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),
and [TN3115 state-restoration relaunch rules](https://developer.apple.com/documentation/technotes/tn3115-bluetooth-state-restoration-app-relaunch-rules).

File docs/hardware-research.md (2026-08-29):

# Hardware research and recommendation

Research and prices checked 2026-07-25. This regional snapshot uses UAE prices
in AED for a consistent comparison; it does not assume contributors are in the
UAE. Marketplace prices move constantly and shipping can cost more than the
parts, so the purchase links below are primarily stable search links and the
prices are realistic ranges rather than quotes.

## Executive recommendation

Prototype without solder on a **38-pin ESP32 DevKit**,
**0.96-inch 128x64 SSD1306 OLED**, and **BH1750/GY-302**. Build the travelling
version around an **ESP32-C3 Super Mini**, a **red 1.2-inch four-digit TM1637
module**, the same ambient-light module, and a
**battery-backed DS3231 RTC**. Assemble it on 2.54 mm perfboard with socket
headers so the ESP and sensors remain replaceable. Power the display, sensor and
RTC from the C3's regulated 3.3 V rail so no ESP pin is exposed to 5 V.

The C3 is the smallest, least expensive suitable controller in the compared
set while retaining both 2.4 GHz Wi-Fi and BLE. The 1.2-inch display sets a
roughly 130 x 50 mm front face: still a small travel-alarm-clock form, but large
enough to meet the stated two-metre viewing distance without depending on
perfect eyesight. The core travel-build hardware is approximately **AED
40–98**, excluding shipping, enclosure, cable, and power supply.

There is one important product limitation: **a standards-only Bluetooth
connection cannot automatically obtain local time from every Android and iOS
phone without phone software or user interaction**. BLE Current Time Service is
useful on compatible iPhones, but is not universal. The implemented initial source order is:

1. retain the last valid UTC time in the DS3231;
2. accept UTC and current offset from an authorized phone through the custom
   encrypted BLE write service;
3. expose a no-installed-app SoftAP captive page that automatically transfers
   the phone browser's epoch and current offset after the user joins the AP;
4. try each truly open Wi-Fi BSSID once per boot and use NTP for UTC while
   retaining the last phone-confirmed offset; after an NTP failure, make one
   bounded synthetic-data-only captive-portal attempt before the final retry.

The captive-page path needs one phone action ("join `ESPClock-xxxx`"), but no form,
account, app, Wi-Fi password, or manual time entry. It is the most painless
cross-platform fallback technically available.

BLE runs alone for 10 seconds on a cleared clock, then coexists with the setup
portal until the two-minute mark before NTP fallback starts. The first
successful route is persisted: BLE refreshes every six hours, while portal and
NTP routes refresh every 24 hours after a 90-second opportunity for BLE to
take over. A later accepted BLE update permanently promotes either Wi-Fi route
and stops Wi-Fi activity. This avoids powering all discovery paths forever
while retaining BLE as the highest-priority upgrade.

## ESP board comparison

| Board | Radio capability | Typical board size / USB | Useful observations | Verdict |
|---|---|---|---|---|
| Classic ESP32, 38-pin | 2.4 GHz 802.11b/g/n, Bluetooth Classic and BLE 4.2 | about 54.4 x 27.9 mm, usually Micro-USB | Dual-core 240 MHz and many GPIOs, but much larger; Classic Bluetooth adds no useful phone-time standard | Excellent bench prototype, unnecessarily large final board |
| ESP32-C3 Super Mini | 2.4 GHz 802.11b/g/n and BLE 5; no Classic Bluetooth | about 22.5 x 18 mm, USB-C | 160 MHz RISC-V, 4 MB flash on common boards, 11 exposed GPIOs; enough for two display pins and one I2C bus | **Recommended** |
| ESP32-C3 Super Mini Plus | Same C3 radios | about 22.5 x 18 mm, USB-C; external-antenna connector | GPIO8 WS2812 RGB LED; fixed power indicator | Supported OLED variant; use its dedicated profile |
| LOLIN/Wemos S2 Mini | 2.4 GHz 802.11b/g/n; **no Bluetooth radio** | 34.3 x 25.4 mm, USB-C | Plenty of GPIO and native USB, but cannot satisfy the primary BLE requirement | Reject |
| ESP32-C6 Mini N4 | 2.4 GHz 802.11b/g/n/ax, BLE 5.3, 802.15.4 Thread/Zigbee | roughly 22.5 x 18 mm for the generic Super Mini, USB-C | 160 MHz RISC-V, 512 KB SRAM, 4 MB flash. Better/newer radio feature set, but Thread, Zigbee and Wi-Fi 6 do not help this clock; board costs roughly twice a C3 and its hobby-board ecosystem is younger | Good drop-in alternative, not enough benefit here |

Authoritative radio references:

- Espressif's [classic ESP32 datasheet](https://www.espressif.com/sites/default/files/documentation/esp32_datasheet_en.pdf)
  describes it as a Wi-Fi + Bluetooth + BLE SoC; its
  [DevKitC guide](https://docs.espressif.com/projects/esp-dev-kits/en/latest/esp32/esp32-devkitc/user_guide.html)
  includes board schematics and dimensions.
- Espressif describes the
  [ESP32-C3](https://www.espressif.com/en/products/socs/esp32-c3) as a
  Wi-Fi and Bluetooth 5 LE device; the
  [current datasheet](https://documentation.espressif.com/esp32-c3_datasheet_en.pdf)
  is the electrical authority.
- Espressif's [ESP32-S2 product page](https://www.espressif.com/en/products/socs/esp32-s2)
  and [datasheet](https://documentation.espressif.com/esp32-s2_datasheet_en.html)
  specify Wi-Fi only. Wemos specifies the
  [S2 Mini as 34.3 x 25.4 mm](https://docs.wemos.cc/en/latest/s2/s2_mini.html).
- Espressif's [ESP32-C6 product page](https://www.espressif.com/en/products/socs/esp32-c6)
  and [current datasheet](https://documentation.espressif.com/esp32-c6_datasheet_en.pdf)
  specify Wi-Fi 6, BLE 5.3 and 802.15.4.

The C3 Super Mini is a generic design, not one tightly controlled product.
Inspect the received board for the expected ESP32-C3 marking and test Wi-Fi/BLE
range before encapsulating it. Some very cheap clones have mediocre ceramic
antenna layout. Do not put copper, perfboard ground plane, a coin cell, epoxy
filled with conductive pigment, or metal case hardware immediately above or in
front of the antenna end. If a particular C3 has poor RF range, substitute a C6
Mini N4 before redesigning anything.

Physical comparison on 2026-07-25 demonstrated why this qualification is a
hard gate. One bare Super Mini received ten nearby Wi-Fi networks (strongest
-67 dBm) but emitted neither a minimal service-bearing BLE advertisement nor a
minimal open SoftAP at 5–10 cm, before or after a full RF-calibration/NVS erase.
A second bare Super Mini on the same cable and identical pinned toolchain
emitted the service advertisement at -48 to -45 dBm and a channel-1 SoftAP at
-34 to -35 dBm. That isolates the failed board's shared RF transmit
path/matching hardware; an API reporting “advertising active” or “SoftAP
started” is not an over-the-air acceptance result.

The C3 Super Mini Plus is also a generic board family. The tested-style Plus
board has a WS2812 RGB LED on GPIO8. The firmware can send a black RGB frame,
but this does not remove power from the LED controller. Its separate power
indicator has no GPIO control. Use the dedicated
`esp32-c3-super-mini-plus-oled-128x64` profile only after the board is identified
as this Plus variant. The board description and pin assignment are documented
by [ESPBoards](https://www.espboards.dev/esp32/esp32-c3-super-mini-plus/) and the
[published Plus V2 schematic](https://mischianti.org/wp-content/uploads/2026/02/ESP32-C3-SuperMINI-V2-schema.pdf).

## Display choice

### Recommended: red 1.2-inch TM1637 clock module

Search for exactly **`1.2 inch 4 digit TM1637 red clock display module`**:

- [AliExpress search](https://www.aliexpress.com/wholesale?SearchText=1.2+inch+4+digit+TM1637+red+clock+display)
- [Amazon.ae search](https://www.amazon.ae/s?k=1.2+inch+4+digit+TM1637+red+clock+display)

Expected price is AED 15–40; Amazon.ae stock is intermittent. Confirm the listing
actually says **TM1637**, **four digits**, **clock colon**, and **red** rather
than buying a visually similar bare display. Red remains legible at much lower
perceived room illumination than blue or white and is kinder in a dark bedroom.
The common assembled board is roughly 120–127 x 40–50 mm with approximately
30 mm digits. It is markedly more comfortable at two metres than the common
14 mm hobby clock modules.

The TM1637 provides eight brightness commands, with a lowest on-duty of 1/16
([TM1637 datasheet](https://datasheet.lcsc.com/szlcsc/Shenzhen-Titan-Micro-Elec-TM1637_C20001.pdf)).
At night, combine the lowest setting with a dark red/smoked acrylic window or
neutral-density film. The filter is important because some displays remain too
bright at their minimum code. Avoid slow software blinking as a dimming method;
visible flicker is unpleasant beside a bed.

Power the complete module from 3.3 V so its CLK/DIO pull-ups cannot drive an ESP
pin above 3.3 V. This is a common and deliberately simple ESP32 hookup, and red
LEDs have enough forward-voltage headroom, but the TM1637 manufacturer's
published electrical-characteristic table is measured at 4.5–5.5 V. Therefore
3.3 V brightness and cold-start operation on the **exact purchased 1.2-inch
module are hardware acceptance gates**, not assumptions. If it does not pass,
the robust remedy is 5 V display power plus a two-channel BSS138 bidirectional
level shifter on CLK/DIO; never connect a 5 V-powered module directly to ESP
GPIO. Also watch the C3 board's 3.3 V rail during Wi-Fi transmit at full display
brightness: generic Super Mini regulators vary. If it falls below 3.1 V or
resets, give the display its own adequately-rated 3.3 V regulator from USB VBUS,
with common ground and the same 3.3 V CLK/DIO logic.

### Compact alternative

A **red 0.56-inch four-digit TM1637 module** costs only AED 4–10 and shrinks the
front face to roughly 55 x 30 mm, but its 14 mm digits are borderline at the
specified two metres and it is rejected for the first build. An HT16K33
1.2-inch backpack is readable but usually costs more and its 5 V I2C pull-ups
require level translation, with no benefit to this four-digit clock. A
continuously-lit OLED is still a weaker final-build choice because it has a
smaller useful digit height and is susceptible to long-term burn-in. However,
the two supported OLED sizes are excellent solderless bring-up displays. The
0.96-inch 128x64 unit is the first test target. The narrow 0.91-inch module is
normally 128x32, giving roughly half the available digit height. Firmware
profiles support both; two-metre readability remains a physical acceptance
gate.

## Ambient-light sensor

Use a **BH1750FVI GY-302 I2C ambient-light breakout**, powered at 3.3 V. Search
**`GY-302 BH1750 light sensor module`**:

- [AliExpress search](https://www.aliexpress.com/wholesale?SearchText=GY-302+BH1750+light+sensor+module)
- [Amazon.ae search](https://www.amazon.ae/s?k=GY-302+BH1750+light+sensor)

Expected cost is AED 3–8 from AliExpress, usually more in an Amazon multipack.
ROHM specifies a digital 16-bit I2C ambient-light sensor with an approximately
1–65,535 lux range, visible-light response designed to reduce IR influence, and
0.5 lux resolution in high-resolution mode 2; see the
[BH1750FVI datasheet](https://www.robotpark.com/image/data/PRO/91421/bh1750fvi-e.pdf).
The IC supply range is 2.4–3.6 V, so powering a GY-302 breakout from 3.3 V keeps
both power and I2C levels ESP-safe. The lowest readings are coarse compared with
more expensive sensors, but the clock only needs to select a minimum night
level, not measure scientific sub-lux differences.

Put the sensor behind its own clear or lightly frosted aperture on the front or
top of the enclosure. Shield it from direct light leaking from the seven-segment
display, otherwise the brightness loop can oscillate. Use a 5–10 second filtered
average plus hysteresis, and map lux logarithmically to the eight display
levels. One-shot high-resolution measurements provide the same one-second
brightness input while allowing the sensor to return to power-down between
conversions.

## RTC and backup power

A DS3231 is not needed to count time while USB remains powered; the ESP system
clock can do that. It **is needed for the promised unplug, travel, and plug-in
experience**: the ESP's clock does not survive complete removal of power, and a
phone or open network may not be available at the next boot.

The DS3231 maintains time from its battery input when main power disappears and
is specified to ±2 ppm from 0–40 °C by Analog Devices
([product page and datasheet](https://www.analog.com/en/products/ds3231.html)).
Store UTC in the DS3231 and retain the last timezone/offset separately in ESP
NVS. An RTC preserves an already-known instant; it cannot discover the new
timezone after travel.

Search **`DS3231 RTC module CR2032`**:

- [AliExpress search](https://www.aliexpress.com/wholesale?SearchText=DS3231+RTC+module+CR2032)
- [Amazon.ae search](https://www.amazon.ae/s?k=DS3231+RTC+module)

Budget AED 6–15 for the module and AED 2–5 for a branded CR2032.

### Coin-cell hazard

The DS3231 IC itself correctly supports a primary coin cell, but many large blue
**ZS-042/HW-111 modules add a diode and roughly 200-ohm resistor intended to
charge an LIR2032**. A normal CR2032 is not rechargeable. Do not put a CR2032 in
such a board until the charge path has been disabled by removing the series
resistor or diode and continuity/voltage has been checked. This module teardown
shows the issue and modification:
[DS3231 module charging circuit](https://electronics.stackexchange.com/questions/134725/ds3231-module-circuit-teardown).

Prefer a breakout explicitly documented for a non-rechargeable CR2032 and with
no charge path. Whichever module is used, power its VCC from 3.3 V, verify with a
multimeter that powered VBAT never rises above the cell's own voltage, and do
this test before potting or giving the clock to a child. Do not substitute a
cheap LIR2032: the crude module circuit is not a good lithium-ion charger.
Button cells are a severe ingestion hazard, so the finished case must retain the
cell behind screws; a friction lid, exposed holder, or tool-free battery door is
not acceptable.

## BLE phone-time feasibility

The Bluetooth SIG
[Current Time Service (CTS), UUID 0x1805](https://www.bluetooth.com/wp-content/uploads/Files/Specification/HTML/CTS_v1.0/out/en/index-en.html)
defines a GATT **server** that exposes local date/time and optionally local UTC
offset/DST information to a GATT **client**. It does not require every phone OS
to host that server.

### iOS

Apple's accessory guidance has documented the iOS GATT Current Time Service for
connected accessories, so an ESP acting as the GATT client can read it on
compatible iPhones. However, iOS system services are not guaranteed to be
available immediately or in every connection state; use Service Changed and
discovery rather than assuming a fixed handle. See Apple's current
[Accessory Design Guidelines](https://developer.apple.com/accessories/Accessory-Design-Guidelines.pdf)
and the analogous service-availability warning in Apple's
[Apple Media Service reference](https://developer.apple.com/library/archive/documentation/CoreBluetooth/Reference/AppleMediaService_Reference/Specification/Specification.html).

This still does not make a generic ESP accessory universally "pair from
Settings and forget." Modern Apple setup APIs such as
[AccessorySetupKit](https://developer.apple.com/documentation/accessorysetupkit/setting-up-and-authorizing-a-bluetooth-accessory)
are app-driven. Generic GATT devices are normally found and connected by a
CoreBluetooth app; the Bluetooth Settings UI is reliable for OS-supported
accessory profiles, not arbitrary custom GATT products. Masquerading as a
keyboard, audio device, or other unrelated profile merely to appear in Settings
would be confusing and is not recommended.

### Android

Android does not expose CTS as a universal system service. The Android Open
Source Project explicitly says
["Android doesn't support this out of box"](https://source.android.com/docs/automotive/time/time_zone_options)
and that phone CTS support covers too little of the market to rely upon.
Android's BLE documentation also describes an
[application acting as the GATT client](https://developer.android.com/develop/connectivity/bluetooth/ble/connect-gatt-server);
pairing alone does not cause Android to write its clock into an accessory.

Android Settings can pair supported accessories, but generic BLE behavior
varies by vendor/version and newer systems can require an app to connect to the
GATT service. The iPhone app can keep separate connections to many clocks, but
each clock firmware still permits only one connected phone. Therefore the
firmware may advertise and bond with multiple phones, but a bond must not be
interpreted as a time source. "Any number" also cannot literally mean infinite
stored bonds: flash is finite. The build permits up to 16 stored bonds and 16
persisted notification records, allows new pairing only during the visible
boot window, and evicts the first bond enumerated by NimBLE rather than claiming
a true LRU policy. Only one BLE connection is compiled into each clock because
the tiny protocol has one global synchronization transaction. The clock remains
ownerless; any compatible family phone can take a turn sequentially.

The current custom service is advertised in a connectable legacy PDU with an
explicit, non-truncated split: flags, complete 128-bit service UUID, and
preferred connection intervals consume 27 primary-advertisement bytes; the
complete 13-character `ESPClock-xxxx` name consumes 15 scan-response bytes.
Bondability is negotiated after connection and is not represented by a generic
advertising-data “pairable” flag. The two-minute new-phone window retains the
30–60 ms discovery cadence already proven with AccessorySetupKit; afterward the
same connectable payload uses an 800–1000 ms cadence for lower-duty bonded
reconnects. A physical BLE scanner and iPhone remain the authority for radio,
timing, background reconnect, and AccessorySetupKit discovery acceptance.

### Practical no-app fallback

When automatic sources fail, start a WPA2-free local AP named
`ESPClock-xxxx` and a captive portal. The page needs no controls: JavaScript
reads `Date.now()` plus the browser's current UTC offset, sends both to the ESP,
shows the confirmed result, and disconnects. This works in normal browsers on iOS and Android
without an installed app. It still requires the user to join that Wi-Fi network;
print a short instruction and QR code on the case. A Web Bluetooth page is not a
cross-platform replacement because Safari/iOS does not provide the same general
Web Bluetooth workflow as Chromium Android.

## Open-Wi-Fi limitations

Only attempt networks whose scan result explicitly reports no link-layer
authentication. Never try guessed passwords and never treat a similarly-named
network as the same network: track failures by BSSID for the current boot.
After association, require DHCP; a successful bounded NTP response is the
implemented Internet/time proof. Mark that BSSID failed on association timeout,
DHCP timeout, NTP failure, or total-window exhaustion, and do not retry it until
the next boot. After an initial NTP failure, the implemented best-effort worker
uses an HTTP interception probe and may accept up to three fixed-capacity
same-origin guest/terms forms with a non-persisted synthetic identity before
retrying NTP once. It rejects credentials, payments, CAPTCHA/OTP, vouchers,
membership, reservation, room-number, JavaScript-only, malformed, and oversized
flows. Portal TLS is deliberately unverified because a new clock may not yet
have trustworthy UTC.

[RFC 8908](https://www.rfc-editor.org/info/rfc8908) and
[RFC 8910](https://www.rfc-editor.org/info/rfc8910) standardize CAPPORT portal
state/discovery and a human-facing URL, not portable form semantics. The pinned
Arduino/lwIP stack does not surface DHCP option 114 without framework changes,
so the firmware retains the intercepted HTTP connectivity probe.

NTP returns UTC, not the local timezone. Automatic local display on open Wi-Fi
therefore also needs an IP-geolocation/timezone HTTPS service. That adds an
external-service dependency and exposes the network's public IP to the chosen
provider. Captive portals commonly block NTP and HTTPS until terms are accepted,
and random open networks remain untrusted. The synthetic autofill improves some
simple portals but cannot make open Wi-Fi reliable or authenticated. Open Wi-Fi
remains a bounded best-effort fallback, never the foundation of correct time.

## Bill of materials

| Qty | Part | Selection notes | AliExpress estimate | Amazon.ae estimate |
|---:|---|---|---:|---:|
| 1 | 38-pin ESP32 DevKit | Solderless reference target | AED 15–30 | AED 25–55 |
| 1 | 0.96-inch SSD1306 128x64 OLED | Default bench display profile | AED 5–12 | AED 15–35 |
| 1 | 0.91-inch SSD1306 OLED, likely 128x32 | Optional comparison profile | AED 4–10 | AED 15–30 |
| 1 | ESP32-C3 Super Mini or Plus, 4 MB, USB-C | Travel target; verify radio, pinout, and Plus GPIO8 LED | AED 9–18 | AED 20–45 |
| 1 | TM1637 1.2-inch red 4-digit module with centre colon | Buy an assembled module, not bare digits | AED 15–40 | AED 35–70 |
| 1 | BH1750FVI GY-302 I2C breakout | Power at 3.3 V; ADDR tied low/default | AED 3–8 | AED 10–30 |
| 1 | DS3231 RTC breakout | Cheap units are clone-risk; qualify drift and verify no cell charger | AED 6–15 | AED 20–45 |
| 1 | Branded CR2032 | Only after charge-path check | AED 2–5 | AED 5–10 |
| 1 | 5 x 7 cm single-sided 2.54 mm perfboard | Cut down after test | AED 3–7 | AED 10–20/pack |
| 2 | 8-pin 2.54 mm female socket strips | Socket the C3; cut longer strip to size | AED 1–3 | AED 8–15/pack |
| 1 | 100 µF, ≥10 V electrolytic plus 100 nF ceramic | Display bulk/rail decoupling | AED 1–2 | usually from assortment |
| — | 24–28 AWG solid wire, solder, heat-shrink, red smoked window | Workshop consumables | AED 3–8 allocated | AED 10–25 |

The core travel configuration (C3, TM1637, BH1750, RTC/cell, perfboard, sockets,
and decoupling) is approximately **AED 40–98 from AliExpress** before shipping,
enclosure, cable, and power supply. Including the listed consumables allowance
brings it to approximately **AED 43–106**. The default bench configuration
(38-pin ESP32, 128x64 OLED, and BH1750) is approximately **AED 23–50**.
Amazon.ae commonly requires multipacks, making the checkout total higher even
though spare parts remain.

## Prototype-board wiring

Recommended C3 Super Mini pin assignment (confirm silkscreen against the actual
board before soldering):

| C3 pin | Connection | Notes |
|---|---|---|
| 3V3 | BH1750/GY-302 VCC; DS3231 VCC; TM1637 VCC | Never connect this rail to 5 V |
| GND | Every module GND | One common ground |
| GPIO3 | TM1637 DIO | Bidirectional display data |
| GPIO4 | TM1637 CLK | Bit-banged display clock |
| GPIO6 | I2C SDA to BH1750 SDA and DS3231 SDA | Shared 3.3 V bus |
| GPIO7 | I2C SCL to BH1750 SCL and DS3231 SCL | Shared 3.3 V bus |
| GPIO8 | On-board LED/strapping pin | Leave untouched on a standard C3; the dedicated Plus profile uses it only for the onboard WS2812 after boot |
| GPIO9 | Existing BOOT button | Hold five seconds after normal boot, then release, to clear sync trust/offset/bonds and restart; never require it in daily use |

I2C addresses are compatible: BH1750 is `0x23` with ADDR low/default (`0x5C`
with ADDR high) and DS3231 is `0x68`. The TM1637 bus only resembles I2C and
remains on its own GPIO4/GPIO3 pair. Most I2C breakout boards already contain
pull-ups. With power disconnected, measure resistance from SDA/SCL to 3.3 V; do
not blindly parallel extra pull-ups. A combined effective value around 2.2–10
kΩ is appropriate for these short, 100 kHz wires.

```text
                              USB-C
                                |
                         C3 Super Mini
                                |
       3V3 -----+----------------+----------------+------ TM1637 VCC
                |                |                |         + 100 uF
            BH1750/GY-302     DS3231              |             |
              0x23             0x68               |        common GND
 GPIO6 SDA ----SDA--------------SDA               |
 GPIO7 SCL ----SCL--------------SCL               |
 GPIO4 CLK --------------------------------------- TM1637 CLK
 GPIO3 DIO --------------------------------------- TM1637 DIO
 GND ----------------------------------------------------- all grounds
```

Layout the display at the front, BH1750 at a shaded top/front aperture, and
the C3 antenna at a case edge with clear space. Place the 100 µF capacitor
between display 3.3 V and ground close to the display. Route the I2C wires
together and keep all signal wires short. Use socket strips for the ESP and
connectors or strain relief for the display/sensor wires. After all tests pass,
trim the perfboard and secure heavy modules with neutral-cure electronics-safe
silicone or printed clips.

Do **not** pour ordinary hardware-store acetic-cure silicone over electronics;
its cure chemistry can corrode copper. Do not pot the first prototype in epoxy:
potting makes the RTC cell, USB connector, and failed modules unserviceable and
can detune the antenna. A screwed case with internal strain relief is the better
first build. If later conformal coating or potting is desired, leave the antenna,
USB-C connector, BH1750 optical window, socketed ESP, and coin cell accessible.

## Hardware acceptance tests before enclosure

1. Flash over USB-C repeatedly and verify automatic boot without pressing BOOT.
2. Run a 24-hour display test at all brightness codes; confirm the minimum plus
   selected filter is visible but does not illuminate a dark room.
3. Compare BH1750 readings in full dark, bedroom light, room light, and sunlit
   room; ensure display light does not materially change the reading.
4. Unplug USB for at least one hour, then verify DS3231 continuity and drift.
5. With USB powered, measure VBAT and prove the CR2032 is not being charged.
6. Exercise BLE and Wi-Fi at 5 m with the intended case materials temporarily in
   place; reject a poor-antenna C3 before assembly.
7. Let Wi-Fi transmit at maximum display brightness for an hour from a marginal
   5 V USB supply; there must be no brownout, flicker, spontaneous reset, hot
   regulator, or 3.3 V rail below 3.1 V.
8. Test the complete sync UX on at least one current iPhone and two unrelated
   Android brands. Verify the custom bonded GATT write with compatible clients
   and verify captive-portal time transfer on both phone families.

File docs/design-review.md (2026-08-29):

# Adversarial design review

> **Review record, not build authority.** This document deliberately preserves
> provisional alternatives and worst-case requirements raised during design.
> Conflicts were resolved in favour of the current stacks in `README.md` and
> `hardware/wiring.md`: a full-size ESP32 with a 128x64 OLED for
> solderless bring-up, then a 3.3 V red 1.2-inch TM1637 with a tested BSS138/5 V
> fallback for the compact build. Follow those two files when wiring.

Status: **conditional go, product dependency resolved for iPhone**. The
repository now includes the recommended iOS 18+ AccessorySetupKit/Core Bluetooth
companion. One app can manage independent persistent connections to many clocks,
while each clock still accepts one connected phone. The design retains the
no-app captive portal and RTC fallbacks. A phone
still does not automatically connect to an arbitrary BLE peripheral and
volunteer its clock merely because it was paired; the app and initial
phone-level approval are required. Fresh onboarding, encrypted synchronization,
remove/re-add, and reboot reconnect passed on an iPhone 17 Pro running iOS
26.5.2. Oldest-supported-iOS coverage, out-of-range return, restoration while
locked/backgrounded, and a six-hour request remain release gates.

The companion's fresh-install lifecycle is authorization-first: it activates
only `ASAccessorySession`, presents the picker without a central manager,
retains `.accessoryAdded`, and constructs Core Bluetooth only after
`.pickerDidDismiss`. An already-authorized relaunch constructs the stable
restoration manager from `.activated`. This ordering is automated-test covered.
Physical picker discovery and authorization without broad Bluetooth access
passed on the current-release device above; the remaining device/version gates
are recorded in `ios/README.md`.

This review treats a wrong-but-plausible displayed time as the primary failure,
followed by a clock that is hard for a child or parent to recover.

## Product contract that must be made explicit

1. **"Zero configuration" can only mean zero configuration after onboarding.**
   A companion phone app can discover the clock, obtain Bluetooth permission,
   perform a one-tap association, and then update it on later boots. Android's
   official BLE flow has an app scan for, connect to, and exchange data with the
   peripheral; its companion-device API likewise does not create the connection
   itself. iOS provides Core Bluetooth/AccessorySetupKit to an app for the same
   purpose. There is no portable OS feature that lets an unknown accessory pull
   local time and timezone from any nearby phone without user authorization.
   See the official [Android BLE
   overview](https://developer.android.com/develop/connectivity/bluetooth/ble/ble-overview),
   [Android companion pairing
   documentation](https://developer.android.com/develop/connectivity/bluetooth/companion-device-pairing),
   and [Apple AccessorySetupKit
   documentation](https://developer.apple.com/documentation/accessorysetupkit/).
2. **BLE Current Time Service is a wire format, not automatic handset
   behavior.** The Bluetooth SIG specification says the CTS *server* exposes
   local time to a client. It does not require a phone to advertise that service,
   connect to this product, or reveal location. A conventional ESP peripheral is
   itself the GATT server, the opposite role from the desired pull operation.
   See the [Bluetooth Current Time Service
   specification](https://www.bluetooth.com/wp-content/uploads/Files/Specification/HTML/CTS_v1.0/out/en/index-en.html).
3. **NTP provides UTC, not location or civil-time rules.** SNTP can set the
   epoch, while timezone conversion is a separate setting in ESP-IDF. See the
   [NTP specification](https://www.rfc-editor.org/info/rfc5905/) and
   [ESP-IDF system-time
   documentation](https://docs.espressif.com/projects/esp-idf/en/v5.0/esp32/api-reference/system/system_time.html).
   A phone/app must provide the current offset and DST rules, or an Internet
   geolocation/timezone service must be added. IP geolocation is imperfect
   around VPNs, carrier gateways, borders, and satellite/aircraft networks.
4. **"Any number of phones" cannot mean unlimited stored bonds or simultaneous
   connections.** Persistent bond storage is finite; ESP-NimBLE's documented
   default maximum is three. The practical requirement should be “any family
   phone may update it sequentially, with a documented finite trusted-device
   cache and deterministic eviction.” See
   [`CONFIG_BT_NIMBLE_MAX_BONDS`](https://docs.espressif.com/projects/esp-idf/en/stable/esp32/api-reference/kconfig-reference.html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).

### Ideal future source priority

Use one explicit arbitration policy, never “last packet wins”:

1. authenticated companion-app write containing UTC epoch, UTC offset, timezone
   identity/rules, uncertainty, and source age;
2. HTTPS timezone/time service over a network that has proven Internet access;
3. SNTP for UTC while retaining the last known timezone;
4. battery-backed RTC plus last known timezone.

Store the RTC in UTC. Store civil-time metadata separately with a checksum and
version. A BLE payload should carry at least: protocol version, Unix time,
offset in minutes, phone-observed timezone ID, the next DST transition and
post-transition offset (or an equivalent POSIX rule), source age, and an
authenticator. Quarter-hour zones, half-hour zones, DST, and International Date
Line changes must not be approximated as whole hours.

If no fresh timezone source exists after travel, the clock must continue with
the previous timezone and show a subtle “stale/not location-confirmed” state.
Silently presenting old-zone time as synchronized is unacceptable.

## Prioritized risks and required actions

### P0 — resolve before claiming the requirements are met

#### 1. Phone synchronization has an unstated app dependency

**Failure:** the ESP advertises forever, but nearby iOS/Android phones do
nothing. Pairing in the Bluetooth Settings screen alone does not implement a
custom time transfer.

**Required action:** choose and document one of these honest product definitions:

- **Recommended:** a tiny Android/iOS companion app with one-tap first use,
  background reconnect where the OS permits, and a visible “open the app”
  recovery path. Subsequent normal use can approach plug-and-play, but background
  delivery is best effort: iOS may suspend/terminate an app and Android imposes
  background-work constraints. Apple's [background BLE
  documentation](https://developer.apple.com/library/archive/documentation/NetworkingInternetWeb/Conceptual/CoreBluetooth_concepts/CoreBluetoothBackgroundProcessingForIOSApps/Perform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)
  explicitly notes that connections can be lost if the process is terminated;
  Android documents comparable [background BLE
  constraints](https://developer.android.com/develop/connectivity/bluetooth/ble/background).
- **Reduced scope:** no app; BLE exposes a service usable by a manual GATT tool,
  while the real automatic source is Internet plus a timezone API. This is not
  “automatic from any phone.”

Do not make firmware completion imply that the end-to-end phone feature exists.

#### 2. Timezone acquisition is not designed

**Failure:** NTP succeeds in Dubai after a flight from Paris, but the RTC remains
Paris civil time; or the current offset works until the next DST transition.

**Required action:** make timezone an independently validated result. A sync is
“fully synchronized” only when both UTC and current civil-time rule/offset are
fresh. The app should derive timezone using phone OS APIs. An Internet fallback
needs a named HTTPS provider, certificate validation, bounded response parsing,
timeouts, and a documented privacy/availability dependency. If only SNTP
succeeds, mark UTC fresh but preserve and visibly flag the stale timezone.

#### 3. Headless BLE security conflicts with painless multi-phone use

**Failure:** a nearby stranger writes a plausible but wrong time, or an attacker
pairs first. With no keyboard/confirmation input, BLE Secure Connections “Just
Works” is still unauthenticated and has no MITM protection; this is explicit in
the [Bluetooth Security Manager
specification](https://www.bluetooth.com/wp-content/uploads/Files/Specification/HTML/Core-54/out/en/host/security-manager-specification.html).

**High-assurance option:** use a per-device random secret and app-layer authentication.
The lowest-friction robust onboarding is a QR code on/inside the case that the
companion app scans once. Derive per-message authentication from that secret and
include a nonce/replay counter. BLE encryption is still worthwhile, but is not
the trust decision. If the project intentionally accepts unauthenticated time
writes, call that out as a conscious low-consequence tradeoff and restrict them
to a short, visibly indicated boot pairing window.

Define conflict behavior: accept the first authenticated, sane, fresh source in
a sync window; reject older/replayed sources; permit a materially newer source
to correct it; rate-limit updates. Never average civil times from multiple
phones.

**Selected v1 disposition:** this clock deliberately accepts the lower-assurance
tradeoff appropriate to a non-safety-critical display. Writes require a bonded,
encrypted connection; new bonds are admitted only during a visibly indicated
two-minute boot window; accepted values are range/plausibility checked and
rate-limited; and one simultaneous BLE connection prevents conflicting writers.
There is no QR secret, numeric comparison, or full replay counter. The
five-minute correction bound rejects captured old values only while the clock
has a valid running-time baseline. After total power loss without a valid RTC,
the next valid synchronization can set the time by any amount. Sixteen bonds
and CCCD records are provisioned;
when full, the first bond enumerated by NimBLE is evicted, not a claimed LRU.

The implemented recovery keeps the on-board BOOT button reachable through a
pinhole: hold it for five seconds while firmware is already running, then
release it to clear sync trust, offset, and bonds and restart. Holding BOOT while
applying power would enter the ROM downloader and is intentionally not the
recovery gesture.

#### 4. Opportunistic open Wi-Fi is a risky, weak fallback

**Failure:** the unit joins a hostile look-alike AP, gets trapped behind a
portal, leaks a stable identifier, accepts spoofed unauthenticated NTP, or
repeatedly burns time trying the same failing network. Portal automation may
also accept terms that were written for a human.

Captive portals are specifically networks that restrict access until user
conditions are fulfilled, typically through a browser. The IETF architecture
does not provide a headless device a universal way to negotiate access; see
[RFC 8952](https://www.rfc-editor.org/info/rfc8952/). The CAPPORT API in
[RFC 8908](https://www.rfc-editor.org/info/rfc8908) and DHCP/RA identification
in [RFC 8910](https://www.rfc-editor.org/info/rfc8910) can advertise portal
state and a human-facing URL, but do not standardize the portal's forms. The
pinned Arduino/lwIP stack also does not expose DHCP option 114 without a
framework change, so the implemented automator keeps HTTP interception as its
discovery mechanism.

**Required action:** treat this as optional, last-resort, compile-time-enabled
behavior—not as a reliable requirement:

- attempt only truly open APs and never guess passwords;
- if portal automation is enabled, accept only fixed-capacity ordinary HTML
  guest/terms forms with per-attempt synthetic data; reject credentials,
  payments, challenges, unsupported encodings, and every documented overflow;
- key the “attempted this boot” set by **BSSID**, not only SSID, and cap the set;
- sort candidates deterministically, enforce short association/DHCP/Internet
  timeouts, try each BSSID once per boot, cap the total number and total elapsed
  time, then turn Wi-Fi off;
- prove Internet access before calling it success; distinguish associated,
  DHCP-complete, captive, DNS-failed, and Internet-reachable states;
- do not expose admin servers, OTA, secrets, or local-network discovery while on
  these networks; retain no AP beyond the current boot;
- use TLS with normal certificate/hostname validation for timezone APIs. A
  battery RTC supplies the approximate time needed for certificate validation.
  SNTP itself is not authenticated and must be treated as lower trust;
- randomize the station identity where supported and never send child/family
  identifiers or telemetry.

**Selected v1 disposition:** opportunistic joining and bounded portal
automation are enabled in normal builds. After an initial NTP failure, a
low-priority worker performs an interception probe, follows at most five
redirects, and submits at most three same-origin URL-encoded forms within 45
seconds. It checks terms boxes and uses only a random per-attempt synthetic
name, reserved email/phone values, and fixed placeholders. Portal HTTPS is
intentionally unverified because the clock may not yet have trustworthy UTC.
The worker cannot use passwords, payments, CAPTCHA/OTP, vouchers, membership,
reservation, or room data; never persists its cookies or identity; and must
still obtain an acceptable NTP result. This is an explicit availability-over-
portal-authentication tradeoff, not a universal captive-portal protocol.

#### 5. Power loss destroys time without an external RTC

**Failure:** after a flight with the unit unplugged, neither phone nor network is
available and the device starts at an invalid epoch.

**Required action:** fit a DS3231-class battery-backed RTC and store UTC. The
DS3231 is specified for 3.3 V operation, battery backup, and ±2 ppm at 0–40 °C;
see the [manufacturer's
datasheet](https://www.analog.com/en/products/ds3231.html). Check and surface its
oscillator-stop/invalid-time condition at boot.

Use a **non-charging** holder/module with a primary CR2032. Many cheap DS3231
boards contain a charging path intended for a rechargeable cell; do not charge a
CR2032. The coin cell must be captive behind a screwed enclosure because button
cells are a severe ingestion hazard. Do not permanently pot a replaceable cell.

### P1 — hardware and usability risks

#### Platform choice

Use **ESP32-C3 for the travel build**. Use a 38-pin ESP32 DevKit for
solderless bring-up; its GPIO21/22 I2C pins make the OLED and BH1750 easy to
test. The C3 has 2.4 GHz Wi-Fi and Bluetooth LE 5, is much smaller than the
original board, and is ample for display, RTC, sensor, BLE, and
occasional Wi-Fi. ESP32-S2 is disqualified because it has no Bluetooth; ESP32-C6
adds protocols this project does not use. Espressif's [chip
comparison](https://docs.espressif.com/projects/esp-idf/en/v5.0/esp32s2/hw-reference/chip-series-comparison.html)
and [Bluetooth support
table](https://docs.espressif.com/projects/esp-idf/en/v5.2/esp32/api-guides/bluetooth.html)
support this choice.

For first bring-up, an official ESP32-C3-DevKitM-1 is the lower-risk reference.
The inexpensive “C3 Super Mini” is a third-party family, not one controlled
board design: qualify the exact batch for USB enumeration, reset/boot behavior,
Wi-Fi/BLE RSSI, 5 V pin behavior, regulator temperature, and continuous
operation before freezing the travel build. Do not use GPIO18/19 for peripherals
on a native-USB C3 design; Espressif assigns them to USB D−/D+.

#### Display selection and logic levels

Test a **0.96-inch 128x64 OLED first** through the modular SSD1306
backend. It should yield larger digits than the narrow 0.91-inch unit, normally
128x32. Both require a two-metre test and have an always-on pixel-aging risk.
For the travel build, use a **red 1.2-inch four-digit seven-segment display**
unless an OLED passes those gates. A 0.56-inch module is a
needless readability risk at two metres, while an OLED/TFT adds backlight glow,
cost, and viewing-angle concerns. Red is preferable at low night brightness.
Verify the actual module through a two-metre day/night viewing test before case
design.

The following HT16K33 discussion records a rejected alternative. The selected
TM1637 design and its acceptance gate are documented in `hardware/wiring.md`.
An HT16K33 backpack is attractive but is not automatically a 3.3 V part. Holtek
specifies HT16K33A operation at 4.5–5.5 V and 16 global brightness levels in its
[display-driver
guide](https://www.holtek.com/webapi/148997/guide.pdf). Generic 5 V boards may
pull SDA/SCL to 5 V, which is unsafe for ESP32 pins. Use either:

- a backpack explicitly providing separate 5 V LED power and 3.3 V logic I/O;
  or
- a proper bidirectional I²C level shifter, with pull-ups to 3.3 V on the ESP
  side and 5 V on the display side.

Do not rely on “3.3 V usually reads as high at 5 V.” Verify low-level night
brightness; 1/16 may still be too bright. A dark red neutral-density window and,
if needed, a driver-enable/supply-dimming scheme must not introduce visible
flicker.

#### Ambient-light control

Use a digital lux sensor such as BH1750-class on the 3.3 V I²C bus. Place it
behind a clear/tinted aperture where the display cannot illuminate it. Apply a
several-second low-pass filter, hysteresis, rate limiting, and a hand-tuned
piecewise/logarithmic lux-to-brightness curve. Define safe behavior for sensor
failure: conservative low brightness at night is more important than maximum
day visibility.

Pairing and stale-status animations must obey the same brightness ceiling. No
full-brightness boot flash is acceptable in a dark bedroom.

On a C3 Super Mini Plus, the dedicated 128x64 profile sends an all-zero frame
to the GPIO8 WS2812 RGB LED during firmware startup. The board's fixed power
indicator remains a hardware limitation because it has no GPIO control.

#### Power and prototype construction

- The compact travel build powers its qualified TM1637 module from 3.3 V. If that
  exact module fails the documented electrical/readability test, use the
  documented 5 V plus BSS138 fallback; never expose the C3 pins to 5 V.
- Use one common ground. Add 100 nF local decoupling at every module and
  100–470 µF near the display/5 V entry to absorb multiplexing/radio transients.
  Validate worst case with all segments at maximum brightness while Wi-Fi
  transmits.
- Keep the 3.3 V I²C section on one side of the level shifter and the 5 V
  display on the other. Use one effective pull-up pair per side. Keep wiring
  short and use soldered perfboard, not removable Dupont jumpers, in the final
  unit.
- Provide strain relief for USB-C and every inter-board wire. The USB connector
  must not be the structural mounting point. Make reset/BOOT recoverable through
  recessed holes.
- Keep copper, wiring, display metal, epoxy, and the enclosure away from the C3
  antenna keep-out. Measure radio range in the finished enclosure.
- Potting is not a substitute for mechanical support. It impedes repair and can
  stress connectors/sensors or detune the antenna. If used, use electronics-safe
  neutral-cure silicone or a characterized low-exotherm compound; never use
  acetic-cure household silicone, cover the antenna/sensor aperture, or encapsulate
  the coin cell/USB connector.

### P2 — state-machine and maintenance quality

Use explicit non-blocking states with deadlines:

`BOOT_SELF_TEST → RTC_DISPLAY → BLE_ONLY → BLE_PLUS_PORTAL →
OPTIONAL_OPEN_WIFI_NTP → ROUTE_SPECIFIC_REFRESH`. A boot with an already
selected route displays valid RTC time immediately. First route selection
instead keeps a steady `PAIR` indication for its two-minute onboarding
sequence; networking must never leave the screen blank.

**Selected source and power disposition:** a cleared clock gives BLE 10 seconds
alone, then runs BLE and the captive portal together until two minutes after
boot. Only then may it try open-Wi-Fi/NTP, bounded to 10 minutes. The first
successful BLE, portal, or NTP source is persisted as the refresh route. BLE
routes refresh every six hours without starting Wi-Fi. Portal and NTP routes
refresh every 24 hours after a 90-second BLE promotion opportunity; portal
refresh leaves its AP available until success, while an NTP route may try the
bounded captive-portal automator before a final NTP retry and then backs off
for another day. A later accepted BLE write promotes either Wi-Fi route and
immediately tears Wi-Fi down. Failed open BSSIDs remain excluded for the
current boot.

BLE retains its proven fast advertisement throughout the two-minute new-phone
window, then uses low-duty connectable advertising for bonded reconnects.
Periodic refresh never replaces or blinks valid time. OLED levels above night
mode add one static 3×3 top-right overdue marker; full-night level 0 and TM1637
add no refresh light or animation.

C3 application profiles must use 80/40 MHz dynamic frequency scaling and
Bluetooth controller modem sleep. The processor and controller return to their
active states for scheduled work. Automatic CPU light sleep must stay
disabled. Do not use deep sleep, change BLE range or timing, or delay
recovery-button polling as a power shortcut.

The four-digit display needs an unambiguous but quiet state vocabulary documented
in the README, for example:

- steady OLED colon with alternating one-minute perimeter fill/drain above
  full-night level 0, or normal TM1637 colon cadence: valid local time;
- brief slow colon pulse: looking for sync;
- distinct dot/colon pattern: pairing available;
- persistent subtle dot: UTC/RTC valid but timezone stale;
- unmistakable startup pattern: RTC invalid.

Outside the explicit first-route `PAIR` sequence, do not alternate away from
valid time. A parent should be able to diagnose the state without a serial
cable, while a sleeping child should not see a light show.

## Acceptance test checklist

No item below should be replaced by “works on my phone.”

### Time and timezone

- [ ] Cold boot with valid RTC and a selected route shows time within two
      seconds, regardless of radio availability; a cleared route instead
      shows steady `PAIR` for the documented onboarding sequence.
- [ ] Cold boot with invalid/missing RTC never shows a plausible invented time;
      it shows the invalid/pairing state.
- [ ] BLE synchronization is demonstrated on iOS 18 and current iOS, including
      first AccessorySetupKit authorization, backgrounded app, system
      termination/restoration, clock power-cycle reconnect, Bluetooth off, and
      permission denied. A user force-quit is verified to require reopening the
      app. The no-app portal is tested on current Android and iOS.
- [ ] Onboarding and recovery steps match the documented “painless” claim and
      require no serial console.
- [ ] Test vectors cover UTC−12, UTC+14, +05:30, +05:45, a DST spring gap, a DST
      fall fold, year/month rollover, leap day, and a west/east International
      Date Line flight.
- [ ] With only SNTP available, UTC becomes fresh while the old timezone remains
      visibly stale; the firmware does not infer a timezone from UTC.
- [ ] RTC remains within the stated tolerance after 24 hours and seven days
      unpowered; missing/flat battery and oscillator-stop flag are detected.
- [ ] A backward time correction, large forward correction, corrupt payload,
      out-of-range date, stale payload, and replayed payload are handled
      deterministically and cannot crash or wrap the display.

### BLE trust and multiple phones

- [ ] An unbonded phone cannot change time outside the two-minute onboarding
      window, and a connected session cannot write until bonding completes.
- [ ] While the clock has a valid running-time baseline, captured old values
      outside the five-minute correction window are rejected. Tests and
      documentation state that this is not cryptographic replay protection and
      that the bound cannot apply after loss of the running baseline.
- [ ] Firmware accepts only one simultaneous BLE connection; two authorized
      iPhones hand off that clock using its automatic-sync toggle without
      oscillation.
- [ ] One iPhone app keeps at least three clocks connected at the same time.
      Each clock's retry, acknowledgement, manual-sync, automatic-sync, and
      removal state remains independent.
- [ ] Fill the trusted/bond cache, add one more phone, reboot, and verify the
      documented first-enumerated eviction behavior. Also cancel a pairing at
      capacity and verify the documented possible eviction/recovery path.
- [ ] Five-second BOOT hold while running, followed by release, clears sync
      trust/offset/bonds, preserves firmware, visibly shows `rSt`, and restarts.
- [ ] Pairing indication is visible at two metres by day and non-disruptive in a
      dark room.

### Open Wi-Fi fallback

- [ ] Test open AP success, association rejection, no DHCP, DNS failure, no
      route, captive portal, TLS interception/bad certificate, UDP/123 blocked,
      and AP disappearance mid-sync.
- [ ] Two APs with the same SSID/different BSSID are tracked separately; one
      BSSID is never retried in the same boot after terminal failure.
- [ ] Candidate count, per-stage timeout, total fallback duration, memory use,
      and reboot-reset of the attempt set meet documented bounds.
- [ ] No open AP is persisted; no listener/admin/OTA service is reachable; no
      secret or stable child/family identifier is transmitted.
- [ ] A spoofed NTP answer cannot override a fresher authenticated phone source,
      and the display/source-quality state reflects lower trust.
- [ ] Button-only and common guest/terms forms are attempted with only the
      documented synthetic values; credentials, payments, challenges,
      oversized/malformed input, and cross-origin form actions fail closed.
- [ ] Portal automation remains within three submissions, five redirects, 45
      seconds, and its fixed response/request/form/control/cookie capacities;
      BLE cancellation cannot apply a stale worker result.

### Display and light sensing

- [ ] All four digits and status indicators are readable at two metres in bright
      room light across the intended viewing angles.
- [ ] In a dark bedroom after settling, the display remains readable without
      noticeably lighting walls/ceiling; evaluate with the actual red window and
      enclosure, not a bare bench module.
- [ ] On each SSD1306 geometry, level 0 uses its sparse dot-matrix face without
      the decorative perimeter; its outer digit footprint matches levels 1–7,
      digits remain unambiguous at the intended distance, and temporary status
      text remains readable. Do not accept a nominally lower contrast command
      that blanks the qualified panel.
- [ ] Sweep from darkness through normal indoor light to bright daylight:
      transitions are monotonic, take several seconds, do not hunt, and show no
      visible flicker.
- [ ] Cover/uncover the sensor, shine the display toward it, disconnect it, and
      inject bad readings; feedback and failure do not cause bright flashes.
- [ ] Boot, pairing, and error indications all respect the current brightness
      ceiling; periodic resync with valid time shows only the normal clock plus
      the steady 3×3 OLED marker above night level 0.

### Electrical, thermal, and mechanical

- [ ] Verify SDA/SCL voltage on both sides of the level shifter; no ESP GPIO ever
      sees 5 V.
- [ ] Test minimum and maximum display brightness with all segments on while
      Wi-Fi and BLE transmit; there are no brownouts, I²C errors, or RTC resets.
- [ ] Test several USB-C supplies/cables, rapid unplug/replug, slow supply ramp,
      and repeated brownouts. Recovery never needs a computer.
- [ ] Run a 72-hour soak with periodic synchronization and forced failures;
      watchdog resets, heap growth, missed display refreshes, and drift are zero
      or within explicitly documented limits.
- [ ] Measure whole-device average and peak current for the two BLE advertising
      cadences, connected low-duty BLE, SoftAP portal, Wi-Fi scan/NTP, and
      minimum/maximum display brightness; verify the 80 MHz C3 clock is stable.
- [ ] Check regulator, display driver, wiring, and enclosure temperature at
      maximum brightness/radio activity.
- [ ] Perform cable/connector tug, one-metre drop in the final enclosure, luggage
      vibration, and at least 100 USB insertion cycles; no perfboard wire or USB
      connector carries enclosure load.
- [ ] Compare BLE/Wi-Fi RSSI and sync success before and after final enclosure or
      potting; antenna performance has not materially regressed.
- [ ] The coin cell is inaccessible without a tool, is clearly identified as
      non-rechargeable, and is replaceable without damaging the unit.

### Reproducibility

- [ ] A clean checkout builds with pinned toolchain/library versions.
- [ ] The documented board target flashes over its USB-C connector and still
      exposes a recovery/download path after bad application firmware.
- [ ] README schematic, pin table, module voltages, I²C addresses, level shifting,
      exact BOM variants, assembly photos/diagrams, and visual-state legend match
      the physical reference build.
- [ ] Automated host-side tests cover time conversion, DST payloads, source
      arbitration, retry/backoff bookkeeping, corrupt persistent storage, and
      brightness mapping.

## Release gate

The hardware/firmware can be called ready to flash when the electrical and
host-side acceptance items pass. The **product** can be called plug-and-play only
after the companion-app path (or an explicitly reduced requirement) is selected
and end-to-end tested. Open-Wi-Fi fallback must remain visibly “best effort”; it
cannot substitute for a phone onboarding decision or promise location-correct
time.

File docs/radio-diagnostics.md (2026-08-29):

# ESP32 incoming-board radio diagnostic

Use this destructive acceptance test on every newly received ESP32-C3 Super
Mini or classic ESP32 DevKit before attaching modules or soldering it into the
clock. It answers a narrow question: can this board flash, boot stably, receive
Wi-Fi, transmit Wi-Fi, advertise/connect over BLE, and complete the companion
app's encrypted GATT exchange?

An ESP-IDF or Arduino API returning success is not an over-the-air test. The
workflow therefore cannot report `PASS` until another device sees the Wi-Fi
beacon and a physical iPhone completes the BLE write and receives the
firmware's `time-accepted` acknowledgement.

## One-command test

Disconnect the display, light sensor, RTC, and other modules. Connect only the
ESP32 using a known-good data cable, then run:

```sh
uv sync
uv run --locked tools/diagnose_esp.py
```

The tool finds a single connected board, infers C3 versus classic from its USB
interface when possible, erases the complete flash without asking, uploads the
matching diagnostic image, and reads its serial results. Erasing the
application, configuration, RF calibration data, and BLE bonds is a deliberate
part of this workflow and has standing project authorization. The ESP rebuilds
RF calibration data on its clean diagnostic boot.

### Agent recovery ladder

An agent must use this order. Do not jump directly from an upload error to
declaring the board defective or asking the user to press BOOT.

1. **Obtain direct serial-device access before starting.** A Codex process may
   be able to list `/dev/cu.*` from its restricted shell while `esptool` still
   cannot open the device. Run the wrapper with approved direct device access
   from the first invocation.
2. **Classify an open failure as a host problem first.** If PlatformIO says
   `Could not open ... the port doesn't exist` but
   `uv run --locked opendle-pio device list`
   still shows that port, stop the restricted run and restart it with direct
   serial access. Also exclude another serial monitor owning the port. This is
   not a BOOT-mode or radio failure.
3. **Use BOOT only after `esptool` can open the port but cannot connect.** Apply
   the board-specific gesture below and let the wrapper retry. A retry is
   recorded, so that run cannot qualify the board.
4. **Recover a board left in the ROM loader correctly.** If serial shows
   `boot: ... DOWNLOAD` or `waiting for download` after upload, release BOOT and
   tap RESET once without touching BOOT. Wait for the wrapper's explicit
   post-flash reset prompt instead of intervening early, so recovery is recorded.
5. **Rerun the complete command from the beginning.** A board may receive
   diagnostic evidence during a recovered run, but it earns `PASS` only when
   erase, upload, normal application boot, heartbeats, and both external radio
   proofs all succeed without manual recovery.

The reference C3 incident established this exact sequence:

1. A sandboxed attempt listed the USB port but could not open it. The agent
   stopped that run instead of treating it as an ESP or BOOT failure.
2. With direct serial access, the full-chip erase and diagnostic upload worked.
3. BOOT had been held through reset, leaving the C3 at `waiting for download`.
   The user released BOOT and tapped RESET once without holding it.
4. The agent kept one serial session open with DTR/RTS inactive so reopening
   the C3's native USB port could not reset the board and destroy BLE evidence.
5. The diagnostic then received nearby Wi-Fi, its SoftAP was visible on the
   phone, and the companion completed an encrypted time write and
   acknowledgement.

Those steps reset software, NVS, bonds, and RF calibration; they did not repair
hardware. Because the board then proved both radios over the air, it was not
classified as defective. The final wrapper performs the non-resetting serial
handling itself. Future agents should run it with direct device access from the
start and rerun from scratch after any manual recovery, rather than repeating
the intermediate tool-debugging attempts above.

If more than one serial device is attached or inference is ambiguous, specify
both:

```sh
uv run --locked tools/diagnose_esp.py \
  --board c3 \
  --port /dev/cu.usbmodem1101
```

The script prints two board-specific names:

- `ESPClock-RadioTest-xxxx`: merely observe this SSID in the phone or
  computer's Wi-Fi picker; joining it is unnecessary.
- `ESPClock-xxxx`: select this in **Add ESPClock** for a new board, or use
  **Sync Now** when that board is already authorized in the physical-iPhone
  companion app; wait for a successful sync.

Answer the two prompts only from what the external device actually did. The
JSON report is written outside the repository under
`/private/tmp/espclock-diagnostics/` unless `--report` selects another path.

## Download-mode recovery

The runner retries a failed erase or upload after showing the appropriate
gesture:

- C3 Super Mini: hold **BOOT**, briefly press **RESET** (or reconnect USB while
  holding BOOT), then release **BOOT**.
- Classic ESP32 DevKit: hold **BOOT**, tap **EN/RESET**, then release **BOOT**.

This powered-reset download gesture is different from the normal firmware's
five-second BOOT recovery gesture. A clone that repeatedly requires manual
download mode can still be diagnosed, but it fails the separate automatic
flashing/cold-start acceptance requirement. Always rerun from the beginning
after recovery; never convert the recovered run itself into `PASS`.

## Result rules

`PASS` requires all of the following in the same run:

1. clean erase and upload complete on the first attempt, followed by exactly
   one stable diagnostic boot and at least three serial heartbeats;
2. SoftAP start plus a completed receive scan containing at least one nearby
   network;
3. external observation of `ESPClock-RadioTest-xxxx`;
4. BLE advertising start, encrypted/bonded connection from the physical
   iPhone, a valid 12-byte time write, and `time-accepted` acknowledgement.

`FAIL` means at least one attempted requirement failed. `INCOMPLETE` means the
automatic checks passed but an over-the-air observation was skipped. In an RF
quiet or shielded location, `--allow-empty-wifi-scan` changes a zero-result
receive scan from `FAIL` to `INCOMPLETE`; it never turns it into a pass.

AccessorySetupKit error 150 is a connection failure, not successful
onboarding. Record it as `no`. When retesting a board whose flash/bonds were
erased, remove its previous ESPClock authorization from the iPhone if iOS
keeps trying stale bond material, then rerun the test.

## Useful modes

Run only the automated portion for build benches or CI-like checks:

```sh
uv run --locked tools/diagnose_esp.py --non-interactive
```

That result is necessarily `INCOMPLETE`, because internal logs do not prove RF
transmission. `--no-erase` also forces `INCOMPLETE`; it exists only for quick
diagnostic-firmware development and cannot qualify an incoming board.

Restore a known product profile after the result is saved:

```sh
uv run --locked tools/diagnose_esp.py \
  --restore-env esp32-c3-oled-128x64
```

Without `--restore-env`, the board intentionally remains on the diagnostic
image. Label rejected boards with the JSON report timestamp and do not assemble
them into a clock.

## What this does not prove

The bare-board check does not qualify five-metre range, enclosure detuning,
display-load brownouts, voltage regulation, sensor buses, cold starts, or
long-duration reliability. Continue with the hardware acceptance tests in the
README after a board passes this gate.

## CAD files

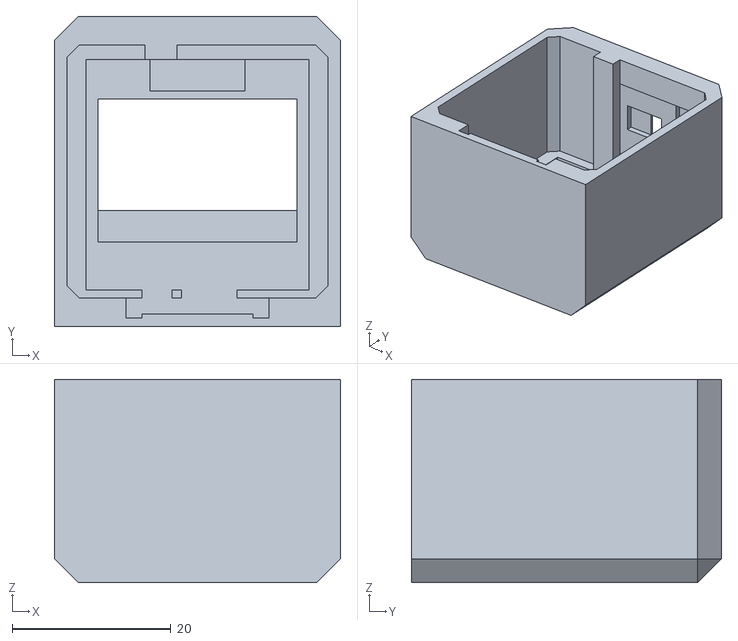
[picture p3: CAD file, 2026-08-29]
hardware/case/front.stl
36.0 x 39.0 x 25.6

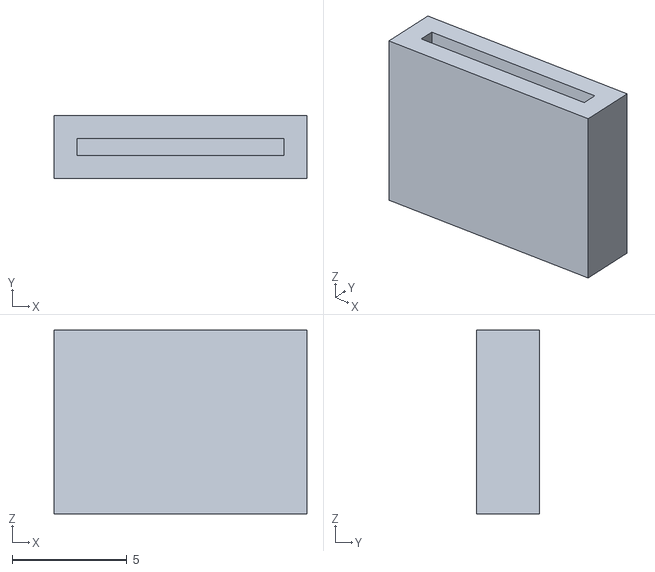
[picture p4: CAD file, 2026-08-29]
hardware/case/cache.stl
11.0 x 2.75 x 8.00

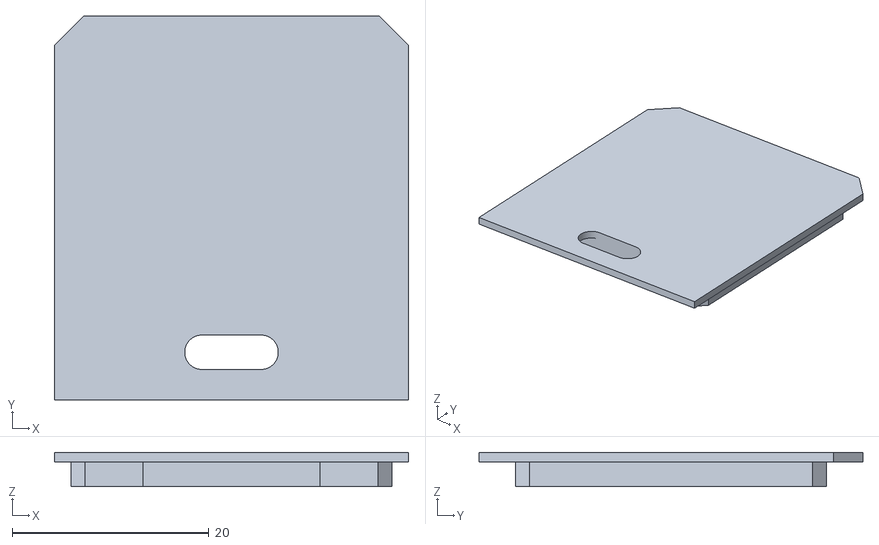
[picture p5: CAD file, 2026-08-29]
hardware/case/back.stl
36.0 x 39.0 x 3.50

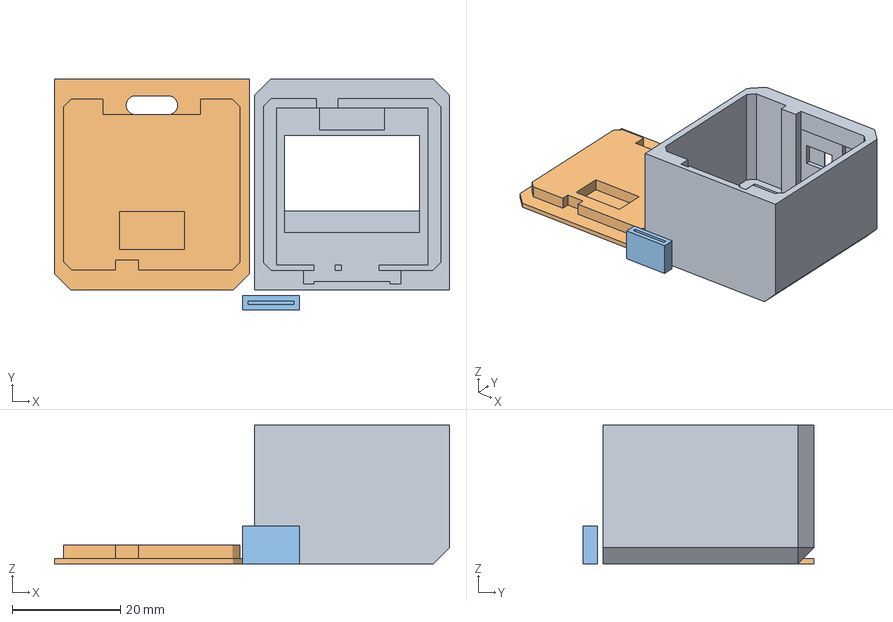
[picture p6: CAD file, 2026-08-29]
hardware/case/esp-clock.3mf
73.0 x 42.7 x 25.6 mm
Front.stl
Back.stl
Cache.stl

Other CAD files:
hardware/case/esp-clock-case.f3d

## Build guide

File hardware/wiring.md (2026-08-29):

# Hardware assembly and wiring

This is the build authority for the solderless bench prototype and the later
compact travel build. The firmware profiles in `platformio.ini` and defaults in
`include/AppConfig.h` must match this file.

## Solderless first prototype

- full-size 38-pin ESP32 DevKit;
- 0.96-inch 128x64 I2C OLED;
- BH1750/GY-302 ambient-light module;
- no DS3231 required for the first functional test;
- breadboard(s) and female-to-female or male-to-female jumpers as appropriate.

Use the `esp32-devkit-oled-128x64` PlatformIO environment. Both modules share
the bus initialized once by the firmware:

| Net | 38-pin ESP32 | SSD1306 OLED | BH1750 | Optional DS3231 |
|---|---|---|---|---|
| `+3V3` | `3V3` | `VCC` | `VCC` | `VCC` |
| `GND` | `GND` | `GND` | `GND` | `GND` |
| `I2C_SDA` | GPIO21 | `SDA` | `SDA` | `SDA` |
| `I2C_SCL` | GPIO22 | `SCL` | `SCL` | `SCL` |

GPIO0 remains connected only to the DevKit's existing BOOT button for the
powered-on five-second recovery gesture. Do not use classic-ESP32 GPIO6/7:
those pins connect to module flash on normal WROOM DevKits. Follow the printed
pin labels, since physical orientation varies. A 38-pin board often covers the
middle breadboard contacts; use two joined breadboards, a wide breadboard, or
jumper one side to a second board.

Expected addresses do not collide: OLED `0x3C` (occasionally `0x3D`), BH1750
`0x23` (`0x5C` with ADDR high), and DS3231 `0x68`. Do not add external I2C
pull-ups blindly: the breakout pull-ups are connected in parallel. If all three
devices are fitted and communication becomes unreliable, measure SDA/SCL
resistance to 3.3 V with power removed and remove one module's pull-up pair if
the effective resistance is excessively low.

The narrow 0.91-inch display is normally 128x32. Move no wires; flash
`esp32-devkit-oled-128x32`. There is no reliable controller query for display
geometry, so these are intentionally separate builds. A malformed or blank
image calls for checking the listing/controller and I2C address, not runtime
auto-detection.

```text
            full-size ESP32 DevKit
         ┌──────────────────────────┐
   3V3 ──┼── OLED VCC ── BH1750 VCC├── optional DS3231 VCC
   GND ──┼── OLED GND ── BH1750 GND├── optional DS3231 GND
GPIO21 ──┼── OLED SDA ── BH1750 SDA├── optional DS3231 SDA
GPIO22 ──┼── OLED SCL ── BH1750 SCL├── optional DS3231 SCL
  GPIO0  │   onboard BOOT only      │
         └──────────────────────────┘
```

With the RTC absent, a successful phone/portal/NTP sync advances normally for
as long as USB remains powered. Complete power loss erases the running instant,
so the next boot must show pairing/no-time and synchronize again. That is a
required bench test, not an error.

### First-breadboard pre-power check

With USB disconnected:

- verify every module's printed `VCC`, `GND`, `SDA`, and `SCL` labels rather
  than relying on connector order;
- confirm `3V3` is not shorted to `GND`;
- confirm SDA and SCL are not shorted to either rail or each other;
- confirm OLED and BH1750 `VCC` connect to `3V3`, never `5V`;
- leave the DS3231 completely disconnected for the first test.

## Compact travel-build stack

- ESP32-C3 Super Mini or Super Mini Plus, 4 MB, USB-C
- red 1.2-inch, four-digit TM1637 module with centre colon
- BH1750/GY-302 ambient-light module
- DS3231 RTC module with a verified non-charging CR2032 arrangement
- 5 x 7 cm, 2.54 mm soldered perfboard
- 100 µF electrolytic and 100 nF ceramic decoupling capacitors
- certified 5 V, 1 A or greater USB supply

## Compact net list

| Net | ESP32-C3 | TM1637 | BH1750 | DS3231 | Other |
|---|---|---|---|---|---|
| `+3V3` | `3V3` | `VCC` | `VCC` | `VCC` | 100 µF positive; 100 nF |
| `GND` | `GND` | `GND` | `GND` | `GND` | capacitor negatives |
| `TM_CLK` | GPIO4 | `CLK` | — | — | keep short |
| `TM_DIO` | GPIO3 | `DIO` | — | — | keep short |
| `I2C_SDA` | GPIO6 | — | `SDA` | `SDA` | 3.3 V pull-ups only |
| `I2C_SCL` | GPIO7 | — | `SCL` | `SCL` | 3.3 V pull-ups only |

Do not use GPIO2, GPIO8, or GPIO9 for modules; they are ESP32-C3 strapping pins. The board's existing GPIO9 BOOT button is intentionally retained for the five-second, powered-on recovery gesture. Leave GPIO18/GPIO19 alone because the Super Mini uses them for native USB.

The C3 Super Mini Plus has a WS2812 RGB LED on GPIO8. For a Plus board with a
128x64 OLED, flash `esp32-c3-super-mini-plus-oled-128x64`. The profile sends an
all-zero RGB frame after the ROM completes its boot-pin checks. Do not connect
an external module to GPIO8. The power indicator is wired to the power rail and
software cannot turn it off. Remove its LED or series resistor only if you have
the exact board schematic and can do the small surface-mount rework safely.

BH1750 address is normally `0x23`; it becomes `0x5C` if the breakout's `ADDR` input is high. DS3231 is `0x68`. The TM1637 signals are not I2C and must stay on their own two pins.

## Compact electrical schematic

```text
 Certified USB-C 5 V supply
             │
      ┌──────┴──────────── ESP32-C3 Super Mini ──────────────┐
      │                                                       │
      │  on-board 3.3 V regulator                             │
      │        │                                              │
      │       3V3───┬──────────┬────────────┬─────||────┐      │
      │             │          │            │    100 nF │      │
      │          TM1637      BH1750       DS3231         │      │
      │          VCC          VCC           VCC          │      │
      │             │          │            │           GND     │
      │             └──────────┴────────────┴─────|(─────┘      │
      │                                          100 µF         │
      │  GPIO4 ─────────────────────────────── TM1637 CLK       │
      │  GPIO3 ─────────────────────────────── TM1637 DIO       │
      │  GPIO6 ───────────── BH1750 SDA ────── DS3231 SDA       │
      │  GPIO7 ───────────── BH1750 SCL ────── DS3231 SCL       │
      │  GND   ────┬──────── TM1637 GND                         │
      │             ├──────── BH1750 GND                         │
      │             └──────── DS3231 GND                         │
      └─────────────────────────────────────────────────────────┘
```

The electrolytic capacitor's stripe is negative and goes to `GND`. Fit the 100 µF capacitor close to the display connector. Fit the 100 nF ceramic across `3V3`/`GND` near the I2C modules.

## DS3231 cell check — mandatory

Many blue ZS-042/HW-111 RTC boards contain a resistor-and-diode charging path intended for an LIR2032. Never install a primary CR2032 until that charge path has been removed or the module is proven non-charging.

1. Inspect the module and find its schematic/listing.
2. For a charging ZS-042-style module, remove the series charging resistor or diode.
3. With no cell fitted, power the module at 3.3 V and measure the holder.
4. Install a branded CR2032.
5. Re-power the board and verify `VBAT` does not rise above the cell's own resting voltage.
6. Put the cell behind a screwed child-resistant enclosure; never pot it permanently.

If the board or charge path cannot be identified confidently, do not use it.

## TM1637 3.3 V acceptance gate

Powering the complete red module at 3.3 V keeps its signal pull-ups safe for the ESP32-C3 and is the simplest first build. The TM1637 manufacturer's guaranteed electrical table is specified at higher supply voltage, so test the exact purchased module before enclosure work:

1. cold-start it repeatedly from a disconnected USB supply;
2. show all segments at brightness levels 0 through 7;
3. transmit Wi-Fi at maximum display brightness for at least 30 minutes;
4. confirm the C3 does not reset and the display does not corrupt;
5. verify two-metre readability in daylight and minimum brightness in a dark bedroom.

If it fails at 3.3 V, power only the display from USB `5V` and put a two-channel BSS138 bidirectional level-shifter module between GPIO4/GPIO3 and the display's `CLK`/`DIO`. The low side is 3.3 V; the high side is 5 V. Never connect a 5 V-powered module's pull-ups directly to ESP pins.

## Perfboard placement

Use [the placement drawing](protoboard-layout.svg) as a routing guide, not as a manufactured-PCB artwork.

- Put the C3 antenna end at or slightly beyond a perfboard/case edge with no copper, coin cell, display metal, or fastener in front of it.
- Socket the C3 so a failed clone can be replaced.
- Keep the USB-C connector exposed and strain-relieved. Do not use it as a structural support.
- Put the BH1750 at a front/top clear aperture, shaded from direct display light.
- Keep the DS3231 and cell accessible after opening the case.
- Solder all final wires. Dupont jumpers are only for bench bring-up.
- Use printed clips or neutral-cure electronics-safe silicone for strain relief. Do not use acetic-cure household silicone.
- Do not pour epoxy on the first prototype. It makes faults, the RTC cell, USB connector, and optical sensor difficult or impossible to service and can detune the antenna.

## Compact-build pre-enclosure continuity checks

With USB and CR2032 removed:

- `3V3` to `GND` is not shorted.
- `5V` to `3V3` is not shorted.
- GPIO3/4/6/7 are not shorted to either rail.
- SDA/SCL resistance to `3V3` indicates sensible effective pull-ups, roughly 2.2–10 kΩ.
- No module net is connected to GPIO2/8/9/18/19.
- On a Super Mini Plus, the onboard RGB LED on GPIO8 is the only permitted use
  of GPIO8 and the dedicated firmware profile is selected.
- Electrolytic polarity is correct.

Continue with the full acceptance checklist in the project README before closing the case.

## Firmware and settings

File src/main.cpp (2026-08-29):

#include <Arduino.h>
#include <Wire.h>
#include <freertos/FreeRTOS.h>

#include "AppConfig.h"
#include "BleTimeService.h"
#include "ClockCore.h"
#include "Diagnostics.h"
#include "DisplayController.h"
#include "NetworkTimeService.h"
#include "TimeKeeper.h"

namespace {
TimeKeeper clockTime;
DisplayController clockDisplay;
BleTimeService bleTime;
NetworkTimeService networkTime;
portMUX_TYPE timeUpdateMux = portMUX_INITIALIZER_UNLOCKED;
TimeUpdate pendingTimeUpdate = {};
bool timeUpdatePending = false;
bool recoveryButtonHeld = false;
bool recoveryResetArmed = false;
uint32_t recoveryButtonPressedMs = 0;

void enqueueTimeUpdate(const TimeUpdate& update) {
  portENTER_CRITICAL(&timeUpdateMux);
  if (clockcore::shouldReplacePendingTimeUpdate(
          timeUpdatePending, pendingTimeUpdate.source, update.source)) {
    pendingTimeUpdate = update;
    timeUpdatePending = true;
  }
  portEXIT_CRITICAL(&timeUpdateMux);
}

bool dequeueTimeUpdate(TimeUpdate& update) {
  bool available = false;
  portENTER_CRITICAL(&timeUpdateMux);
  if (timeUpdatePending) {
    update = pendingTimeUpdate;
    timeUpdatePending = false;
    available = true;
  }
  portEXIT_CRITICAL(&timeUpdateMux);
  return available;
}

void discardSupersededTimeUpdate(const TimeSource appliedSource) {
  portENTER_CRITICAL(&timeUpdateMux);
  if (clockcore::shouldDiscardQueuedTimeUpdate(
          timeUpdatePending, pendingTimeUpdate.source, appliedSource)) {
    timeUpdatePending = false;
  }
  portEXIT_CRITICAL(&timeUpdateMux);
}

void handleRecoveryButton() {
  const uint32_t now = millis();
  const bool pressed = digitalRead(config::kRecoveryButtonPin) == LOW;
  if (pressed) {
    if (!recoveryButtonHeld) {
      recoveryButtonHeld = true;
      recoveryButtonPressedMs = now;
    } else if (!recoveryResetArmed &&
               now - recoveryButtonPressedMs >= config::kRecoveryHoldMs) {
      recoveryResetArmed = true;
      CLOCK_DIAGNOSTIC_PRINTLN(
          "Recovery armed; release BOOT to clear sync trust and BLE bonds");
    }
    return;
  }

  if (recoveryResetArmed) {
    clockTime.clearSyncTrust();
    bleTime.clearBonds();
    CLOCK_DIAGNOSTIC_PRINTLN("Recovery complete; restarting");
    delay(100);
    ESP.restart();
  }
  recoveryButtonHeld = false;
  recoveryResetArmed = false;
}

UserDisplayState displayState() {
  return clockcore::selectUserDisplayState(
      recoveryResetArmed, networkTime.portalActive(), networkTime.wifiBusy(),
      clockTime.hasValidTime(),
      networkTime.setupPairingDisplayActive(),
      networkTime.syncOverdue());
}
}  // namespace

void setup() {
#if CLOCK_ONBOARD_RGB_LED_PIN >= 0
  // The C3 Super Mini Plus uses a WS2812 RGB LED on strapping pin GPIO8.
  // Setup runs after the ROM sampled the strapping pins, so it is safe to
  // transmit an all-zero frame here. The LED then stays dark.
  neopixelWrite(static_cast<uint8_t>(CLOCK_ONBOARD_RGB_LED_PIN), 0, 0, 0);
#endif
#if CLOCK_ENABLE_DIAGNOSTICS
  CLOCK_DIAGNOSTIC_BEGIN(115200);
  delay(100);
#endif
#if CLOCK_CPU_FREQUENCY_MHZ > 0
  if (!setCpuFrequencyMhz(config::kCpuFrequencyMhz)) {
    CLOCK_DIAGNOSTIC_PRINTF("CPU frequency change to %u MHz failed\n",
                            config::kCpuFrequencyMhz);
  }
#endif
  pinMode(config::kRecoveryButtonPin, INPUT_PULLUP);
  Wire.begin(config::kI2cSdaPin, config::kI2cSclPin);

  clockTime.begin();
  clockDisplay.begin();
  bleTime.begin(enqueueTimeUpdate);
  networkTime.begin(enqueueTimeUpdate, clockTime.utcOffsetMinutes(),
                    clockTime.hasConfirmedSync(), clockTime.syncRoute(),
                    clockTime.lastSyncUtc(), clockTime.utcNow());

  CLOCK_DIAGNOSTIC_PRINTF(
      "ESPClock boot: display=%s/%s, light=%s, RTC=%s, time=%s, "
      "offset=%d min, cpu=%u MHz\n",
                clockDisplay.displayName(),
                clockDisplay.displayAvailable() ? "ready" : "missing",
                clockDisplay.lightSensorAvailable() ? "ready" : "missing",
                clockTime.rtcAvailable() ? "present" : "missing",
                clockTime.hasValidTime() ? "valid" : "needed",
                clockTime.utcOffsetMinutes(), getCpuFrequencyMhz());
#if CLOCK_DISPLAY_DRIVER == CLOCK_DISPLAY_SSD1306
  CLOCK_DIAGNOSTIC_PRINTF(
      "OLED configured at I2C address 0x%02X (%dx%d)\n",
      config::kOledAddress, CLOCK_OLED_WIDTH, CLOCK_OLED_HEIGHT);
#endif
}

void loop() {
  handleRecoveryButton();

  TimeUpdate update = {};
  if (dequeueTimeUpdate(update)) {
    const bool applied = clockTime.apply(update);
    if (update.source == TimeSource::kBle) {
      bleTime.reportTimeResult(applied);
    }
    if (applied) {
      networkTime.onExternalTimeSync(update.source,
                                     update.utcOffsetMinutes,
                                     clockTime.utcNow());
      // The applied source has now stopped its lower-priority producers. Drop
      // an update that arrived after dequeue, but keep a later higher-priority
      // update for the next loop.
      discardSupersededTimeUpdate(update.source);
      CLOCK_DIAGNOSTIC_PRINTF(
          "Time synchronized: source=%u epoch=%lld offset=%d\n",
          static_cast<unsigned>(update.source),
          static_cast<long long>(update.unixUtc),
          update.utcOffsetMinutes);
    }
  }

  bleTime.tick(clockTime);
  networkTime.tick(bleTime.connected());
  if (networkTime.takeBleSyncRequest()) {
    bleTime.requestSync();
  }
  clockDisplay.tick(clockTime, displayState(),
                    networkTime.syncOverdue());
  delay(config::kMainLoopDelayMs);
}

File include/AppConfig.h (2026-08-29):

#pragma once

#include <stdint.h>

// Every setting below can be overridden with a PlatformIO -D build flag.
#define CLOCK_DISPLAY_TM1637 1
#define CLOCK_DISPLAY_SSD1306 2

#ifndef CLOCK_DISPLAY_DRIVER
#define CLOCK_DISPLAY_DRIVER CLOCK_DISPLAY_TM1637
#endif

#ifndef CLOCK_TM1637_CLK_PIN
#define CLOCK_TM1637_CLK_PIN 4
#endif

#ifndef CLOCK_TM1637_DIO_PIN
#define CLOCK_TM1637_DIO_PIN 3
#endif

#ifndef CLOCK_I2C_SDA_PIN
#define CLOCK_I2C_SDA_PIN 6
#endif

#ifndef CLOCK_I2C_SCL_PIN
#define CLOCK_I2C_SCL_PIN 7
#endif

#ifndef CLOCK_BH1750_ADDRESS
#define CLOCK_BH1750_ADDRESS 0x23
#endif

#ifndef CLOCK_OLED_WIDTH
#define CLOCK_OLED_WIDTH 128
#endif

#ifndef CLOCK_OLED_HEIGHT
#define CLOCK_OLED_HEIGHT 64
#endif

#ifndef CLOCK_OLED_ADDRESS
#define CLOCK_OLED_ADDRESS 0x3C
#endif

#ifndef CLOCK_FALLBACK_BRIGHTNESS
#define CLOCK_FALLBACK_BRIGHTNESS 2
#endif

#ifndef CLOCK_LIGHT_SENSOR_RETRY_MS
#define CLOCK_LIGHT_SENSOR_RETRY_MS 30000UL
#endif

#ifndef CLOCK_MAIN_LOOP_DELAY_MS
#define CLOCK_MAIN_LOOP_DELAY_MS 20UL
#endif

#ifndef CLOCK_CPU_FREQUENCY_MHZ
#define CLOCK_CPU_FREQUENCY_MHZ 0
#endif

#ifndef CLOCK_ENABLE_OPEN_WIFI_FALLBACK
#define CLOCK_ENABLE_OPEN_WIFI_FALLBACK 1
#endif

#ifndef CLOCK_ENABLE_CAPTIVE_PORTAL_AUTOFILL
#define CLOCK_ENABLE_CAPTIVE_PORTAL_AUTOFILL 1
#endif

#ifndef CLOCK_CAPTIVE_PORTAL_MAX_SUBMISSIONS
#define CLOCK_CAPTIVE_PORTAL_MAX_SUBMISSIONS 3
#endif

#ifndef CLOCK_CAPTIVE_PORTAL_TIMEOUT_MS
#define CLOCK_CAPTIVE_PORTAL_TIMEOUT_MS 45000UL
#endif

#ifndef CLOCK_DEFAULT_UTC_OFFSET_MINUTES
#define CLOCK_DEFAULT_UTC_OFFSET_MINUTES 0
#endif

#ifndef CLOCK_BLE_WINDOW_MS
#define CLOCK_BLE_WINDOW_MS 10000UL
#endif

#ifndef CLOCK_NEW_BLE_PAIRING_WINDOW_MS
#define CLOCK_NEW_BLE_PAIRING_WINDOW_MS 120000UL
#endif

#ifndef CLOCK_BLE_FAST_ADV_MIN_MS
#define CLOCK_BLE_FAST_ADV_MIN_MS 30UL
#endif

#ifndef CLOCK_BLE_FAST_ADV_MAX_MS
#define CLOCK_BLE_FAST_ADV_MAX_MS 60UL
#endif

#ifndef CLOCK_BLE_SLOW_ADV_MIN_MS
#define CLOCK_BLE_SLOW_ADV_MIN_MS 800UL
#endif

#ifndef CLOCK_BLE_SLOW_ADV_MAX_MS
#define CLOCK_BLE_SLOW_ADV_MAX_MS 1000UL
#endif

#ifndef CLOCK_BLE_RESYNC_GRACE_MS
#define CLOCK_BLE_RESYNC_GRACE_MS 90000UL
#endif

#ifndef CLOCK_INITIAL_SETUP_WINDOW_MS
#define CLOCK_INITIAL_SETUP_WINDOW_MS 120000UL
#endif

#ifndef CLOCK_WIFI_CONNECT_TIMEOUT_MS
#define CLOCK_WIFI_CONNECT_TIMEOUT_MS 12000UL
#endif

#ifndef CLOCK_NTP_TIMEOUT_MS
#define CLOCK_NTP_TIMEOUT_MS 18000UL
#endif

#ifndef CLOCK_RESYNC_INTERVAL_MS
#define CLOCK_RESYNC_INTERVAL_MS (6UL * 60UL * 60UL * 1000UL)
#endif

#ifndef CLOCK_WIFI_RESYNC_INTERVAL_MS
#define CLOCK_WIFI_RESYNC_INTERVAL_MS (24UL * 60UL * 60UL * 1000UL)
#endif

#ifndef CLOCK_WIFI_WINDOW_MS
#define CLOCK_WIFI_WINDOW_MS (10UL * 60UL * 1000UL)
#endif

#ifndef CLOCK_LIGHT_SAMPLE_MS
#define CLOCK_LIGHT_SAMPLE_MS 1000UL
#endif

#ifndef CLOCK_ENABLE_DIAGNOSTICS
#define CLOCK_ENABLE_DIAGNOSTICS 0
#endif

#ifndef CLOCK_LIGHT_DIAGNOSTICS
#define CLOCK_LIGHT_DIAGNOSTICS 0
#endif

#ifndef CLOCK_PAIRING_DISPLAY_MS
#define CLOCK_PAIRING_DISPLAY_MS 1500UL
#endif

#ifndef CLOCK_RECOVERY_BUTTON_PIN
#define CLOCK_RECOVERY_BUTTON_PIN 9
#endif

#ifndef CLOCK_ONBOARD_RGB_LED_PIN
#define CLOCK_ONBOARD_RGB_LED_PIN -1
#endif

#ifndef CLOCK_RECOVERY_HOLD_MS
#define CLOCK_RECOVERY_HOLD_MS 5000UL
#endif
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

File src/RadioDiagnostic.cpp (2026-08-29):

#include <Arduino.h>
#include <NimBLEDevice.h>
#include <WiFi.h>

#include <algorithm>
#include <atomic>
#include <cstring>
#include <esp_system.h>

#include "ClockCore.h"

namespace {
constexpr char kServiceUuid[] = "7f510000-1b15-4dc7-9f3f-19b30a6f6a21";
constexpr char kTimeUuid[] = "7f510001-1b15-4dc7-9f3f-19b30a6f6a21";
constexpr char kStatusUuid[] = "7f510002-1b15-4dc7-9f3f-19b30a6f6a21";
constexpr uint32_t kHeartbeatIntervalMs = 2000UL;
constexpr uint32_t kTimeProperties =
    NIMBLE_PROPERTY::READ | NIMBLE_PROPERTY::WRITE |
    NIMBLE_PROPERTY::WRITE_ENC | NIMBLE_PROPERTY::NOTIFY;

NimBLEServer* server = nullptr;
NimBLECharacteristic* statusCharacteristic = nullptr;
std::atomic<uint8_t> connectionCount{0};
std::atomic_bool authenticated{false};
std::atomic_bool bleRoundTripPassed{false};
bool wifiApStarted = false;
bool wifiScanComplete = false;
int wifiNetworkCount = -1;
int wifiStrongestRssi = -127;
uint32_t lastHeartbeatMs = 0;
char bleName[24] = {};
char wifiName[32] = {};

void setStatus(const char* status, const bool notify) {
  statusCharacteristic->setValue(
      reinterpret_cast<const uint8_t*>(status), std::strlen(status));
  if (notify && connectionCount.load() > 0) {
    statusCharacteristic->notify();
  }
}

class ServerCallbacks final : public NimBLEServerCallbacks {
 public:
  void onConnect(NimBLEServer*, ble_gap_conn_desc* description) override {
    ++connectionCount;
    const bool encrypted =
        description != nullptr && description->sec_state.encrypted;
    const bool bonded =
        description != nullptr && description->sec_state.bonded;
    authenticated.store(encrypted && bonded);
    Serial.printf(
        "ESP_DIAG event=ble_connected encrypted=%s bonded=%s\n",
        encrypted ? "yes" : "no", bonded ? "yes" : "no");
    if (description != nullptr && !encrypted) {
      NimBLEDevice::startSecurity(description->conn_handle);
    }
  }

  void onAuthenticationComplete(ble_gap_conn_desc* description) override {
    const bool passed =
        description != nullptr && description->sec_state.encrypted &&
        description->sec_state.bonded;
    authenticated.store(passed);
    Serial.printf("ESP_DIAG event=ble_authenticated result=%s\n",
                  passed ? "pass" : "fail");
    if (!passed && description != nullptr) {
      server->disconnect(description->conn_handle);
      return;
    }
    setStatus("sync-request", true);
  }

  void onDisconnect(NimBLEServer*, ble_gap_conn_desc*) override {
    if (connectionCount.load() > 0) {
      --connectionCount;
    }
    authenticated.store(false);
    const bool restarted = NimBLEDevice::startAdvertising();
    Serial.printf("ESP_DIAG event=ble_disconnected adv_restart=%s\n",
                  restarted ? "yes" : "no");
  }
};

class TimeCallbacks final : public NimBLECharacteristicCallbacks {
 public:
  void onWrite(NimBLECharacteristic* characteristic) override {
    const std::string value = characteristic->getValue();
    int64_t epoch = 0;
    int16_t utcOffsetMinutes = 0;
    const bool validPacket =
        authenticated.load() &&
        clockcore::parseTimeSyncPayload(
            reinterpret_cast<const uint8_t*>(value.data()), value.size(),
            epoch, utcOffsetMinutes);
    bleRoundTripPassed.store(validPacket);
    setStatus(validPacket ? "time-accepted" : "time-rejected", true);
    Serial.printf(
        "ESP_DIAG event=ble_time_write authenticated=%s bytes=%u result=%s\n",
        authenticated.load() ? "yes" : "no",
        static_cast<unsigned>(value.size()),
        validPacket ? "pass" : "fail");
  }
};

class StatusCallbacks final : public NimBLECharacteristicCallbacks {
 public:
  void onSubscribe(NimBLECharacteristic*, ble_gap_conn_desc*,
                   uint16_t subscriptionValue) override {
    if ((subscriptionValue & 0x01U) != 0U) {
      setStatus("sync-request", true);
      Serial.println("ESP_DIAG event=ble_status_subscribed result=pass");
    }
  }
};

void startBle() {
  NimBLEDevice::init(bleName);
  NimBLEDevice::setPower(ESP_PWR_LVL_P9);
  NimBLEDevice::setSecurityAuth(true, false, true);
  NimBLEDevice::setSecurityIOCap(BLE_HS_IO_NO_INPUT_OUTPUT);

  server = NimBLEDevice::createServer();
  server->setCallbacks(new ServerCallbacks());
  NimBLEService* service = server->createService(kServiceUuid);
  NimBLECharacteristic* timeCharacteristic =
      service->createCharacteristic(kTimeUuid, kTimeProperties);
  statusCharacteristic = service->createCharacteristic(
      kStatusUuid, NIMBLE_PROPERTY::READ | NIMBLE_PROPERTY::NOTIFY);
  timeCharacteristic->setCallbacks(new TimeCallbacks());
  statusCharacteristic->setCallbacks(new StatusCallbacks());
  setStatus("time-needed", false);
  service->start();

  NimBLEAdvertisementData advertisementData;
  advertisementData.setFlags(BLE_HS_ADV_F_DISC_GEN |
                             BLE_HS_ADV_F_BREDR_UNSUP);
  advertisementData.setCompleteServices(NimBLEUUID(kServiceUuid));
  advertisementData.setPreferredParams(120, 240);
  NimBLEAdvertisementData scanResponseData;
  scanResponseData.setName(bleName);

  NimBLEAdvertising* advertising = NimBLEDevice::getAdvertising();
  advertising->setAdvertisementData(advertisementData);
  advertising->setScanResponseData(scanResponseData);
  advertising->setScanResponse(true);
  advertising->setMinInterval(48);  // 30 ms in 0.625 ms units.
  advertising->setMaxInterval(96);  // 60 ms in 0.625 ms units.
  const bool started = advertising->start();
  Serial.printf(
      "ESP_DIAG event=ble_ready started=%s name=%s service=%s\n",
      started ? "yes" : "no", bleName, kServiceUuid);
}

void scanWifi() {
  wifiNetworkCount = WiFi.scanNetworks(false, true);
  wifiStrongestRssi = -127;
  if (wifiNetworkCount > 0) {
    for (int index = 0; index < wifiNetworkCount; ++index) {
      wifiStrongestRssi =
          std::max(wifiStrongestRssi, static_cast<int>(WiFi.RSSI(index)));
    }
  }
  WiFi.scanDelete();
  wifiScanComplete = true;
  Serial.printf(
      "ESP_DIAG event=wifi_scan complete=yes networks=%d strongest_rssi=%d\n",
      wifiNetworkCount, wifiStrongestRssi);
}

void printHeartbeat() {
  Serial.printf(
      "ESP_DIAG event=heartbeat uptime_ms=%lu free_heap=%u wifi_ap=%s "
      "wifi_stations=%u wifi_scan_complete=%s wifi_networks=%d "
      "ble_advertising=%s ble_connections=%u ble_authenticated=%s "
      "ble_round_trip=%s\n",
      static_cast<unsigned long>(millis()),
      static_cast<unsigned>(ESP.getFreeHeap()),
      wifiApStarted ? "yes" : "no",
      static_cast<unsigned>(WiFi.softAPgetStationNum()),
      wifiScanComplete ? "yes" : "no", wifiNetworkCount,
      NimBLEDevice::getAdvertising()->isAdvertising() ? "yes" : "no",
      static_cast<unsigned>(connectionCount.load()),
      authenticated.load() ? "yes" : "no",
      bleRoundTripPassed.load() ? "yes" : "no");
}
}  // namespace
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

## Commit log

2026-07-25 Improve OLED brightness and light sensor handling
2026-07-25 Optimize power
2026-07-25 feat: introduce OLED perimeter progress visualization and seconds support
    - API/DisplayBackend: extend showTime signature to include seconds for richer time rendering
    - Display backends: implement second-aware showTime paths and perimeter rendering hook
    - Perimeter logic: add new OledPerimeter module to compute perimeter progress, pixel spans, and rotation
    - Ssd1306DisplayBackend: wire drawPerimeterProgress into showTime path and use second in frameKey
    - Tm1637DisplayBackend: extend showTime signature to accept seconds for parity
    - DisplayController: pass local seconds to showTime for accurate perimeter progress
    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
2026-07-25 feat: add centralized user display state logic and perimeter dithering support
    - Core: implement selectUserDisplayState to decide display mode from recovery, portal, wifi, time validity, pairing, and background refresh intent
    - UI/Main: switch to using clockcore::selectUserDisplayState in displayState() to reflect new logic
    - Network: expose and manage backgroundRefreshActive flag to reflect ongoing non-visual background refresh
    - Perimeter: introduce dithering scheme and isPixelVisible helper to preserve edge visibility under low brightness
    - Display: integrate dithering threshold when drawing perimeter progress and apply brightness dithering before rendering
    - Tests: extend test suite with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
2026-07-26 docs: add printable case assets and preview
    [back.stl, esp-clock-case.f3d, front.stl]
2026-07-26 docs: improve travel wiring diagram
2026-07-28 feat: pin PlatformIO and Starlette versions to fix compatibility and advisories
    - Update pyproject.toml to pin platformio==6.1.20b1 and starlette==1.3.1 for compatibility and advisory clearance
    - Add UV sources block to pin platformio-core rev for reproducible builds
    - Align uv.lock with new pins and git source references to ensure lockfile consistency
    - Reflect updated package versions (platformio 6.1.20b1, starlette 1.3.1) in the lock data to prevent drift
2026-07-30 Reduce ESP32-C3 normal power use
    [partitions-espclock.csv]
2026-08-22 Use shared electronics and ESP32 libraries
2026-08-29 Fix firmware and iOS synchronization faults
    [CaptivePortalAutofillCore.h, ClockCore.h]
2026-08-29 Add Super Mini Plus support and case files
    [back.stl, cache.stl, esp-clock-case.f3d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]
2026-08-30 Protect button-free firmware recovery
